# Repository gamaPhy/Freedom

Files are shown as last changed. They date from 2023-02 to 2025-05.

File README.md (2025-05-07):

# Freedom series Analog Keypads

## Tech Stack

KFC (Kicad, Freecad, C)

## Firmware

<https://github.com/gamaPhy/qmk-keyboards/tree/main/firmware/freedom>

## Images

freedom-3k

## How To

### Create an PCB outline in FreeCAD and import to Kicad

1. Create sketch in FreeCAD
2. Mirror sketch
3. Merge original sketch and mirrored sketch together
4. Export the merged sketch as `filename.dxf` (An Autodesk DXF 2D file)
5. In Kicad, import graphics as an `Edge.Cuts` layer

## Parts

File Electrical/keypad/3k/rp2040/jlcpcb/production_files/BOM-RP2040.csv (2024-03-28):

Comment | Designator | Footprint | LCSC
100n | C1,C11,C18,C19,C2,C20,C21,C22,C23,C24,C25,C26,C27,C28,C29,C3,C30,C31,C32,C33,C34,C35,C36,C37,C38,C4,C5,C6,C7,C8 | C_0402_1005Metric | C1525
47 | R7 | R_0402_1005Metric | C25118
10k | R1,R12,R13 | R_0402_1005Metric | C25744
1u | C12 | C_0402_1005Metric | C52923
12MHz | Y1 | Crystal_SMD_3225-4Pin_3.2x2.5mm | C9002
ME6212C33M5G | U1 | SOT-23-5
1u | C10 | C_1206_3216Metric
5.1k | R5 | C_0402_1005Metric
DRV5056A3QDBZR | U5 | SOT-23
BSS138 | Q1 | SOT-23
PRTR5V0U2X | U3 | SOT-143B
1k | R2 | C_0402_1005Metric
1u | C9 | C_1206_3216Metric
1u | C13 | C_0402_1005Metric
27R | R3 | C_0402_1005Metric
USB-TYPE-C-016 | P1 | USB-TYPE-C-016_Receptacle_DEALON_16P_MidMnt
nSMD050-24V | F1 | Fuse_1206_3216Metric
WS2812B | D2 | LED_WS2812B_PLCC4_5.0x5.0mm_P3.2mm
WS2812B | D5 | LED_WS2812B_PLCC4_5.0x5.0mm_P3.2mm
WS2812B | D7 | LED_WS2812B_PLCC4_5.0x5.0mm_P3.2mm
WS2812-2020 | D3 | LED_WS2812-2020
WS2812B | D9 | LED_WS2812B_PLCC4_5.0x5.0mm_P3.2mm
KAN0644-0551B1-A | SW3 | KAN0644
WS2812B | D1 | LED_WS2812B_PLCC4_5.0x5.0mm_P3.2mm
WS2812B | D6 | LED_WS2812B_PLCC4_5.0x5.0mm_P3.2mm
WS2812B | D8 | LED_WS2812B_PLCC4_5.0x5.0mm_P3.2mm
WS2812-2020 | D4 | LED_WS2812-2020
DRV5056A3QDBZR | U7 | SOT-23
TS-1187A-B-A-B | SW5 | TS-1187A
27R | R4 | C_0402_1005Metric
5.1k | R6 | C_0402_1005Metric
DRV5056A3QDBZR | U6 | SOT-23
TS-1187A-B-A-B | SW4 | TS-1187A
WS2812-2020 | D10 | LED_WS2812-2020
KAN0644-0551B1-A | SW1 | KAN0644
1k | R8 | C_0402_1005Metric
KAN0644-0551B1-A | SW2 | KAN0644
5.1k | R9 | C_0402_1005Metric
5.1k | R10 | C_0402_1005Metric
WS2812-2020 | D11 | LED_WS2812-2020
1u | C15 | C_0402_1005Metric
27p | C17 | C_0402_1005Metric
10n | C14 | C_0402_1005Metric
5.1k | R11 | C_0402_1005Metric
W25Q16JVSS | U2 | SOIC-8_5.23x5.23mm_P1.27mm
27p | C16 | C_0402_1005Metric
RP2040 | U4 | RP2040-QFN-56
WS2812B | D12 | LED_WS2812B_PLCC4_5.0x5.0mm_P3.2mm
WS2812-2020 | D14 | LED_WS2812-2020
WS2812-2020 | D13 | LED_WS2812-2020
WS2812-2020 | D15 | LED_WS2812-2020

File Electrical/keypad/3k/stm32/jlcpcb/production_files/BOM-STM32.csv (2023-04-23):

Comment | Designator | Footprint | LCSC
10n | C14 | C_0402_1005Metric | C15195
100n | C11,C2,C3,C4,C5,C6 | C_0402_1005Metric | C1525
4u7 | C1 | C_0603_1608Metric | C19666
47 | R3 | R_0402_1005Metric | C25118
10k | R4,R5,R6,R7 | R_0402_1005Metric | C25744
1u | C12,C13 | C_0402_1005Metric | C52923
12MHz | Y1 | Crystal_SMD_3225-4Pin_3.2x2.5mm | C9002
10u | C8 | C_1206_3216Metric
ME6208A44M3G | U1 | SOT-23
100n | C17 | C_0402_1005Metric
10u | C7 | C_1206_3216Metric
10u | C10 | C_1206_3216Metric
SLSS49E | U5 | SOT-23
100n | C16 | C_0402_1005Metric
100n | C15 | C_0402_1005Metric
BSS138 | Q1 | SOT-23
5.1k | R1 | C_0402_1005Metric
PRTR5V0U2X | U3 | SOT-143B
ME6212C25M5G | U2 | SOT-23-5
5.1k | R2 | C_0402_1005Metric
27p | C18 | C_0402_1005Metric
10u | C9 | C_1206_3216Metric
4u7 | C20 | C_0805_2012Metric
27p | C19 | C_0402_1005Metric
USB-TYPE-C-016 | P1 | USB-TYPE-C-016_Receptacle_DEALON_16P_MidMnt
nSMD050-24V | F1 | Fuse_1206_3216Metric
100n | C26 | C_0402_1005Metric
100n | C29 | C_0402_1005Metric
100n | C25 | C_0402_1005Metric
100n | C27 | C_0402_1005Metric
WS2812B | D2 | LED_WS2812B_PLCC4_5.0x5.0mm_P3.2mm
100n | C21 | C_0402_1005Metric
100n | C22 | C_0402_1005Metric
WS2812B | D5 | LED_WS2812B_PLCC4_5.0x5.0mm_P3.2mm
100n | C23 | C_0402_1005Metric
WS2812B | D7 | LED_WS2812B_PLCC4_5.0x5.0mm_P3.2mm
WS2812B | D3 | LED_WS2812B_PLCC4_5.0x5.0mm_P3.2mm
WS2812B | D9 | LED_WS2812B_PLCC4_5.0x5.0mm_P3.2mm
BUTT1 | SW3 | PTS647_4.5x4.5mm
WS2812B | D1 | LED_WS2812B_PLCC4_5.0x5.0mm_P3.2mm
WS2812B | D6 | LED_WS2812B_PLCC4_5.0x5.0mm_P3.2mm
WS2812B | D8 | LED_WS2812B_PLCC4_5.0x5.0mm_P3.2mm
100n | C28 | C_0402_1005Metric
WS2812B | D4 | LED_WS2812B_PLCC4_5.0x5.0mm_P3.2mm
100n | C24 | C_0402_1005Metric
GZ2012D601TF | FB1 | C_0805_2012Metric
STM32F401RCTx | U7 | LQFP-64_10x10mm_P0.5mm
Conn_01x04_Socket | J1 | PinSocket_1x04_P2.54mm_Vertical
BUTT2 | SW5 | PTS647_4.5x4.5mm
SLSS49E | U4 | SOT-23
SLSS49E | U6 | SOT-23
BUTT3 | SW4 | PTS647_4.5x4.5mm
WS2812B | D10 | LED_WS2812B_PLCC4_5.0x5.0mm_P3.2mm
100n | C30 | C_0402_1005Metric
TS-1187A-B-A-B | SW2 | TS-1187A
TS-1187A-B-A-B | SW1 | TS-1187A

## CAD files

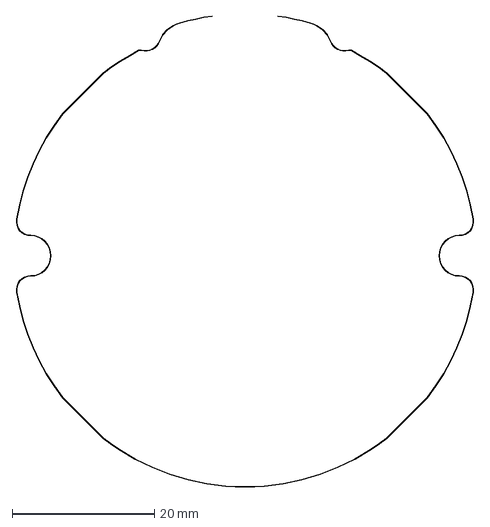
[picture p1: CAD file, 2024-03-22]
Electrical/keypad/3k/pcb-edge-cuts/edge-cuts-Shape.dxf
64.4 x 66.2 mm

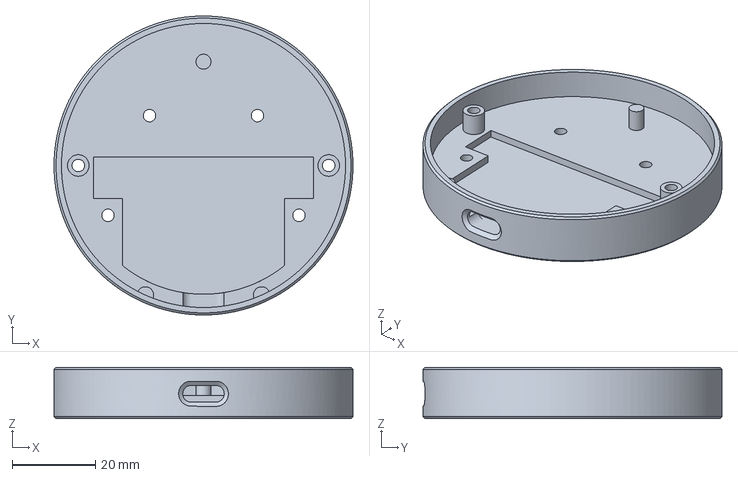
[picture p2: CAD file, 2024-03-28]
Mechanical/keypad/3k/case/Bambu/case-Body.3mf
72.0 x 72.0 x 12.4 mm

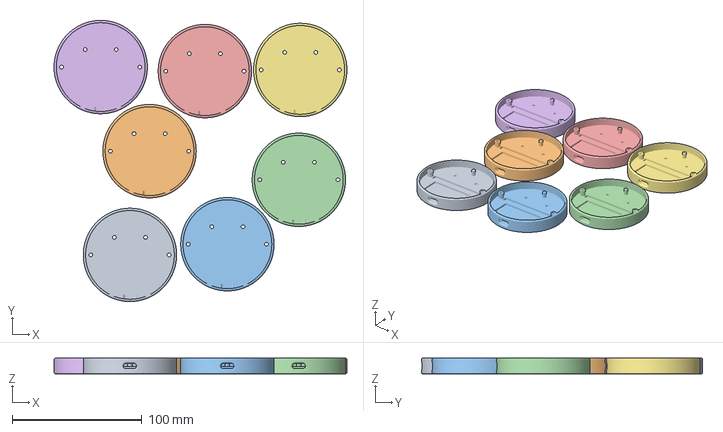
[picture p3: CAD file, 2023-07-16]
Mechanical/keypad/3k/case/Bambu/case-Body-array.3mf
225.8 x 216.7 x 12.2 mm
case-Body.stl x 7

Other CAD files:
Mechanical/keypad/3k/case/case.FCStd
Electrical/keypad/3k/pcb-edge-cuts/edge-cuts.FCStd
Mechanical/keypad/3k/case/case-Body.3mf
Mechanical/keypad/3k/case/case-Body-pla-plus.3mf
Mechanical/keypad/3k/case/case-Body.stl

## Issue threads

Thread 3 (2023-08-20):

HE sensor output value changes depending on LED settings.

tlietz, 2023-08-20:
Should try testing out switching regulators, or find a way to compensate the changes in firmware by detecting when LED settings are changed and getting a new reading for "unpressed".

tlietz, 2023-10-31:
Oversampling was sufficient

Closed 2023-10-31.

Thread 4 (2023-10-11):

Some LED are directly under bare fr4 material of plate

tlietz, 2023-10-11:
This causes jarring light when LED brightness is high.

Should change location of triangles on the plate

tlietz, 2023-11-20:
Actually isn't bad the way it is, can be reopened later if there are complaints about it

Closed 2023-11-20.

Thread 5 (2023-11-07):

Add LED on GPIO25

tlietz, 2023-11-07:
The PICO has an LED on GPIO25. This could be useful for debugging. However, there may be an easy way to repurpose the other LEDs we currently use.

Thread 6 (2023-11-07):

External EEPROM for sensor calibration

tlietz, 2023-11-07:
An external eeprom can be used to store sensor calibration values so that the internal eeprom (or external flash for rp2040) can be factory reset without affecting the calibration values. This will become more important as the number of keys increase.

Closed 2024-03-13.

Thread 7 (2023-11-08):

Uneven underglow

tlietz, 2023-11-08:
The underglow looks uneven, decreasing the radius of the pcb would help. There are already two screws to secure the PCB, so the pcb doesn't need to touch the case walls at all.

tlietz, 2024-03-13:
Decreased radius of pcb to about 2mm less than inner case

Closed 2024-03-13.

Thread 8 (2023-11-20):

Add pads or plated thru holes from rp2040 GPIO pins

tlietz, 2023-11-20:
Breakout some more pins of the rp2040 so that peripherals can be easily hand-wired to the unused I2C and SPI busses.  Also makes it easier to repurpose the board.

tlietz, 2024-03-13:
Added I2c0 and I2c1 plated through-holes with 2.54mm pitch. Decided not to breakout any SPI because it would be hard to find room, and SPI is not that suitable for hand-wiring due to the relatively fast frequencies.

Closed 2024-03-13.

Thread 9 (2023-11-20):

Use non-addressable rgb LEDs and have an IC controller driving them

tlietz, 2023-11-20:
How does power consumption between the LEDs compare? Can more LEDs be used, resulting in more consistent gradients while LED are on?

tlietz, 2024-03-13:
Not needed for small keypad

Closed 2024-03-13.

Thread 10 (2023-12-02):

Temperature drift

tlietz, 2023-12-02:
There is considerable temperature drift when LEDs are on. How can this be improved on a PCB level? How much can it be compensated for in firmware?

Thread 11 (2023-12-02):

Remove all power sources except 3v3

tlietz, 2023-12-02:
Boards have been tested using the 3v3 LDO to power RP2040, the ADC, and the HE sensors. Found that it works just as well as using the 4v4 and 2v5 LDOs since the range of the HE sensor outputs is still large enough.

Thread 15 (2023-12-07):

Find better button solution

tlietz, 2023-12-07:
The current plastic buttons are only 2.4mm in diameter, and I'm developing calluses from using them.
The only plastic buttons that feel good are ones that have a diameter of at least 3mm. However, the base is usually too high to fit between the PCB and plate.

Can also look into silicone, rubber, or plastic caps

Update PCB and plate accordingly

tlietz, 2023-12-07:
Might also be able to use the 4.5x4.5mm buttons that have 2.5mm stem diameter with these caps:
https://www.aliexpress.us/item/3256804597174923.html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,scm-url:1007.40000.326746.0,pvid:f3fe78c0-eed2-4f92-ae2c-fd7d8d456037,tpp_buckets:668%232846%238114%23706&pdp_npi=4%40dis%21USD%214.00%213.6%21%21%214.00%21%21%402101e9ec17019235043287144e413f%2112000030471356784%21rec%21US%21%21AB

Closed 2024-03-07.

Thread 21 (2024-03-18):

Test making only half of the printed standoff for improved lighting

tlietz, 2024-03-18:

tlietz, 2024-03-23:
Only needed if the new LED placement prove to be insufficient

tlietz, 2024-04-27:
no need with current led configuration

Closed 2024-04-27.

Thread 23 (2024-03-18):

Change per-key backlight leds to 2x2mm size

tlietz, 2024-03-18:
Some switches have a thin plastic line that prevents them from being used with the 5050 led package size

Closed 2024-03-22.

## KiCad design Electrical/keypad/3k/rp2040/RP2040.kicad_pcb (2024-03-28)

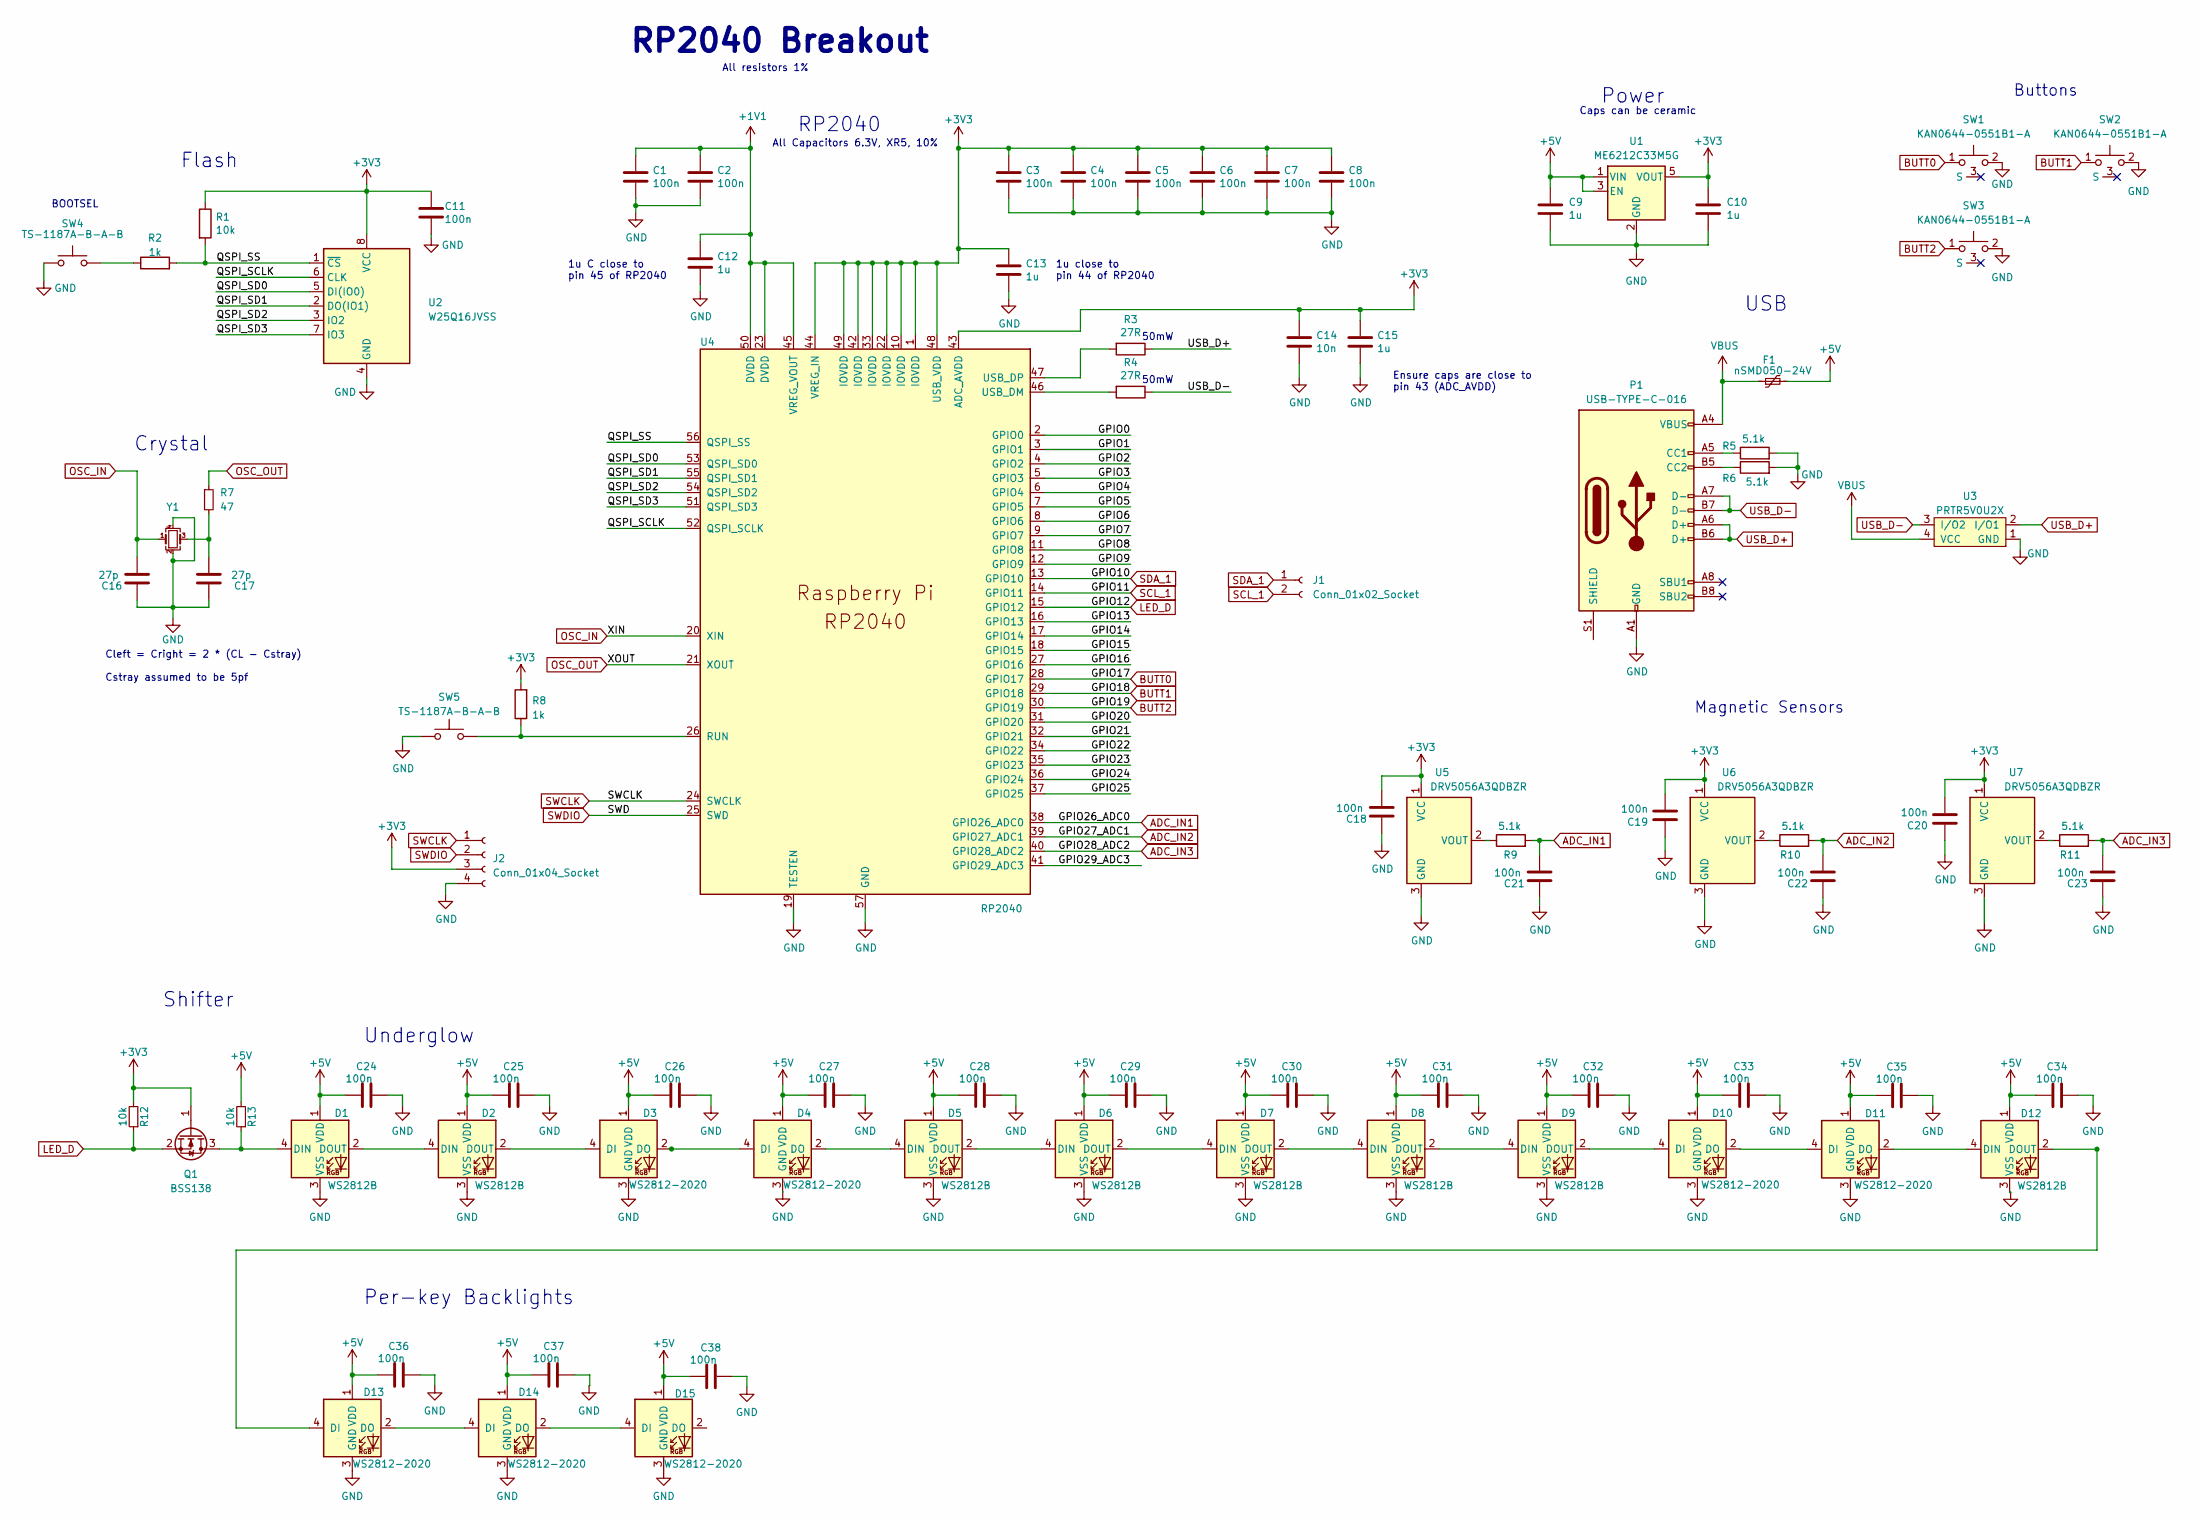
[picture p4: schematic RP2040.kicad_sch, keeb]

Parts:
C1, C2, C3, C4, C5, C6, C7, C8, C11, C18, C19, C20, C21, C22, C23, C24, C25, C26, C27, C28, C29, C30, C31, C32, C33, C34, C35, C36, C37, C38: 100n; C_0402_1005Metric
C9, C10: 1u; C_1206_3216Metric
C12, C13, C15: 1u; C_0402_1005Metric
C14: 10n; C_0402_1005Metric
C16, C17: 27p; C_0402_1005Metric
D1, D2, D5, D6, D7, D8, D9, D12: WS2812B; LED_WS2812B_PLCC4_5.0x5.0mm_P3.2mm
D3, D4, D10, D11, D13, D14, D15: WS2812-2020; LED_WS2812-2020; PARTREV V1.3
F1: nSMD050-24V; Fuse_1206_3216Metric
J1: Conn_01x02_Socket; PinSocket_1x02_P2.54mm_Vertical
J2: Conn_01x04_Socket; PinSocket_1x04_P2.54mm_Vertical
P1: USB-TYPE-C-016; USB-TYPE-C-016_Receptacle_DEALON_16P_MidMnt
Q1: BSS138; SOT-23
R1: 10k; R_0402_1005Metric
R2, R8: 1k; C_0402_1005Metric
R3, R4: 27R; C_0402_1005Metric
R5, R6, R9, R10, R11: 5.1k; C_0402_1005Metric
R7: 47; R_0402_1005Metric; LCSC Part # C25118
R12, R13: 10k; R_0402_1005Metric; LCSC Part # C25744
SW1, SW2, SW3: KAN0644-0551B1-A; KAN0644
SW4, SW5: TS-1187A-B-A-B; TS-1187A
U1: ME6212C33M5G; SOT-23-5
U2: W25Q16JVSS; SOIC-8_5.23x5.23mm_P1.27mm
U3: PRTR5V0U2X; SOT-143B
U4: RP2040; RP2040-QFN-56
U5, U6, U7: DRV5056A3QDBZR; SOT-23
Y1: 12MHz; Crystal_SMD_3225-4Pin_3.2x2.5mm; LCSC Part # C9002

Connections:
+1V1: C1.1, C2.1, C12.1, U4.23 (DVDD), U4.45 (VREG_VOUT), U4.50 (DVDD)
+3V3: C3.1, C4.1, C5.1, C6.1, C7.1, C8.1, C10.1, C11.1, C13.1, C14.1, C15.1, C18.2, C19.2, C20.2, J2.3, Q1.1 (G), R1.1, R8.2, R12.2, U1.5 (VOUT), U2.8 (VCC), U4.1 (IOVDD), U4.10 (IOVDD), U4.22 (IOVDD), U4.33 (IOVDD), U4.42 (IOVDD), U4.43 (ADC_AVDD), U4.44 (VREG_IN), U4.48 (USB_VDD), U4.49 (IOVDD), U5.1 (VCC), U6.1 (VCC), U7.1 (VCC)
+5V: C9.1, C24.1, C25.1, C26.1, C27.1, C28.1, C29.1, C30.1, C31.1, C32.1, C33.1, C34.1, C35.1, C36.1, C37.1, C38.1, D1.1 (VDD), D2.1 (VDD), D3.1 (VDD), D4.1 (VDD), D5.1 (VDD), D6.1 (VDD), D7.1 (VDD), D8.1 (VDD), D9.1 (VDD), D10.1 (VDD), D11.1 (VDD), D12.1 (VDD), D13.1 (VDD), D14.1 (VDD), D15.1 (VDD), F1.2, R13.2, U1.1 (VIN), U1.3 (EN)
/GPIO0: U4.2 (GPIO0)
/GPIO1: U4.3 (GPIO1)
/GPIO2: U4.4 (GPIO2)
/GPIO3: U4.5 (GPIO3)
/GPIO4: U4.6 (GPIO4)
/GPIO5: U4.7 (GPIO5)
/GPIO6: U4.8 (GPIO6)
/GPIO7: U4.9 (GPIO7)
/GPIO8: U4.11 (GPIO8)
/GPIO9: U4.12 (GPIO9)
/GPIO13: U4.16 (GPIO13)
/GPIO14: U4.17 (GPIO14)
/GPIO15: U4.18 (GPIO15)
/GPIO16: U4.27 (GPIO16)
/GPIO20: U4.31 (GPIO20)
/GPIO21: U4.32 (GPIO21)
/GPIO22: U4.34 (GPIO22)
/GPIO23: U4.35 (GPIO23)
/GPIO24: U4.36 (GPIO24)
/GPIO25: U4.37 (GPIO25)
/GPIO29_ADC3: U4.41 (GPIO29_ADC3)
/QSPI_SCLK: U2.6 (CLK), U4.52 (QSPI_SCLK)
/QSPI_SD0: U2.5 (DI(IO0)), U4.53 (QSPI_SD0)
/QSPI_SD1: U2.2 (DO(IO1)), U4.55 (QSPI_SD1)
/QSPI_SD2: U2.3 (IO2), U4.54 (QSPI_SD2)
/QSPI_SD3: U2.7 (IO3), U4.51 (QSPI_SD3)
/QSPI_SS: R1.2, R2.2, U2.1 (~CS), U4.56 (QSPI_SS)
ADC_IN1: C21.2, R9.2, U4.38 (GPIO26_ADC0)
ADC_IN2: C22.2, R10.2, U4.39 (GPIO27_ADC1)
ADC_IN3: C23.2, R11.2, U4.40 (GPIO28_ADC2)
BUTT0: SW1.1, U4.28 (GPIO17)
BUTT1: SW2.1, U4.29 (GPIO18)
BUTT2: SW3.1, U4.30 (GPIO19)
GND: C1.2, C2.2, C3.2, C4.2, C5.2, C6.2, C7.2, C8.2, C9.2, C10.2, C11.2, C12.2, C13.2, C14.2, C15.2, C16.1, C17.1, C18.1, C19.1, C20.1, C21.1, C22.1, C23.1, C24.2, C25.2, C26.2, C27.2, C28.2, C29.2, C30.2, C31.2, C32.2, C33.2, C34.2, C35.2, C36.2, C37.2, C38.2, D1.3 (VSS), D2.3 (VSS), D3.3 (GND), D4.3 (GND), D5.3 (VSS), D6.3 (VSS), D7.3 (VSS), D8.3 (VSS), D9.3 (VSS), D10.3 (GND), D11.3 (GND), D12.3 (VSS), D13.3 (GND), D14.3 (GND), D15.3 (GND), J2.4, P1.A1 (GND), P1.A12 (GND), P1.B1 (GND), P1.B12 (GND), R5.2, R6.2, SW1.2, SW2.2, SW3.2, SW4.1, SW5.1, U1.2 (GND), U2.4 (GND), U3.1 (GND), U4.19 (TESTEN), U4.57 (GND), U5.3 (GND), U6.3 (GND), U7.3 (GND), Y1.2, Y1.4
LED_D: Q1.2 (S), R12.1, U4.15 (GPIO12)
unnamed: C17.2, R7.2, Y1.3
unnamed: D1.4 (DIN), Q1.3 (D), R13.1
unnamed: D1.2 (DOUT), D2.4 (DIN)
unnamed: D2.2 (DOUT), D3.4 (DI)
unnamed: D3.2 (DO), D4.4 (DI)
unnamed: D4.2 (DO), D5.4 (DIN)
unnamed: D5.2 (DOUT), D6.4 (DIN)
unnamed: D6.2 (DOUT), D7.4 (DIN)
unnamed: D7.2 (DOUT), D8.4 (DIN)
unnamed: D8.2 (DOUT), D9.4 (DIN)
unnamed: D9.2 (DOUT), D10.4 (DI)
unnamed: D10.2 (DO), D11.4 (DI)
unnamed: D11.2 (DO), D12.4 (DIN)
unnamed: D12.2 (DOUT), D13.4 (DI)
unnamed: D13.2 (DO), D14.4 (DI)
unnamed: D14.2 (DO), D15.4 (DI)
unnamed: P1.A5 (CC1), R5.1
unnamed: P1.B5 (CC2), R6.1
unnamed: R2.1, SW4.2
unnamed: R8.1, SW5.2, U4.26 (RUN)
unnamed: R4.2, U4.46 (USB_DM)
unnamed: R3.2, U4.47 (USB_DP)
unnamed: R9.1, U5.2 (VOUT)
unnamed: R10.1, U6.2 (VOUT)
unnamed: R11.1, U7.2 (VOUT)
OSC_IN: C16.2, U4.20 (XIN), Y1.1
OSC_OUT: R7.1, U4.21 (XOUT)
SCL_1: J1.2, U4.14 (GPIO11)
SDA_1: J1.1, U4.13 (GPIO10)
SWCLK: J2.1, U4.24 (SWCLK)
SWDIO: J2.2, U4.25 (SWD)
USB_D+: P1.A6 (D+), P1.B6 (D+), R3.1, U3.2 (I/O1)
USB_D-: P1.A7 (D-), P1.B7 (D-), R4.1, U3.3 (I/O2)
VBUS: F1.1, P1.A4 (VBUS), P1.A9 (VBUS), P1.B4 (VBUS), P1.B9 (VBUS), U3.4 (VCC)

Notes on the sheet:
50mW
RP2040 Breakout
Underglow
Crystal
Magnetic Sensors
Per-key Backlights
All Capacitors 6.3V, XR5, 10%
USB
Flash
Ensure caps are close to pin 43 (ADC_AVDD)
1u close to pin 44 of RP2040
1u C close to pin 45 of RP2040
Caps can be ceramic
All resistors 1%
Power
Buttons
Shifter
RP2040
Cleft = Cright = 2 * (CL - Cstray) Cstray assumed to be 5pf
BOOTSEL

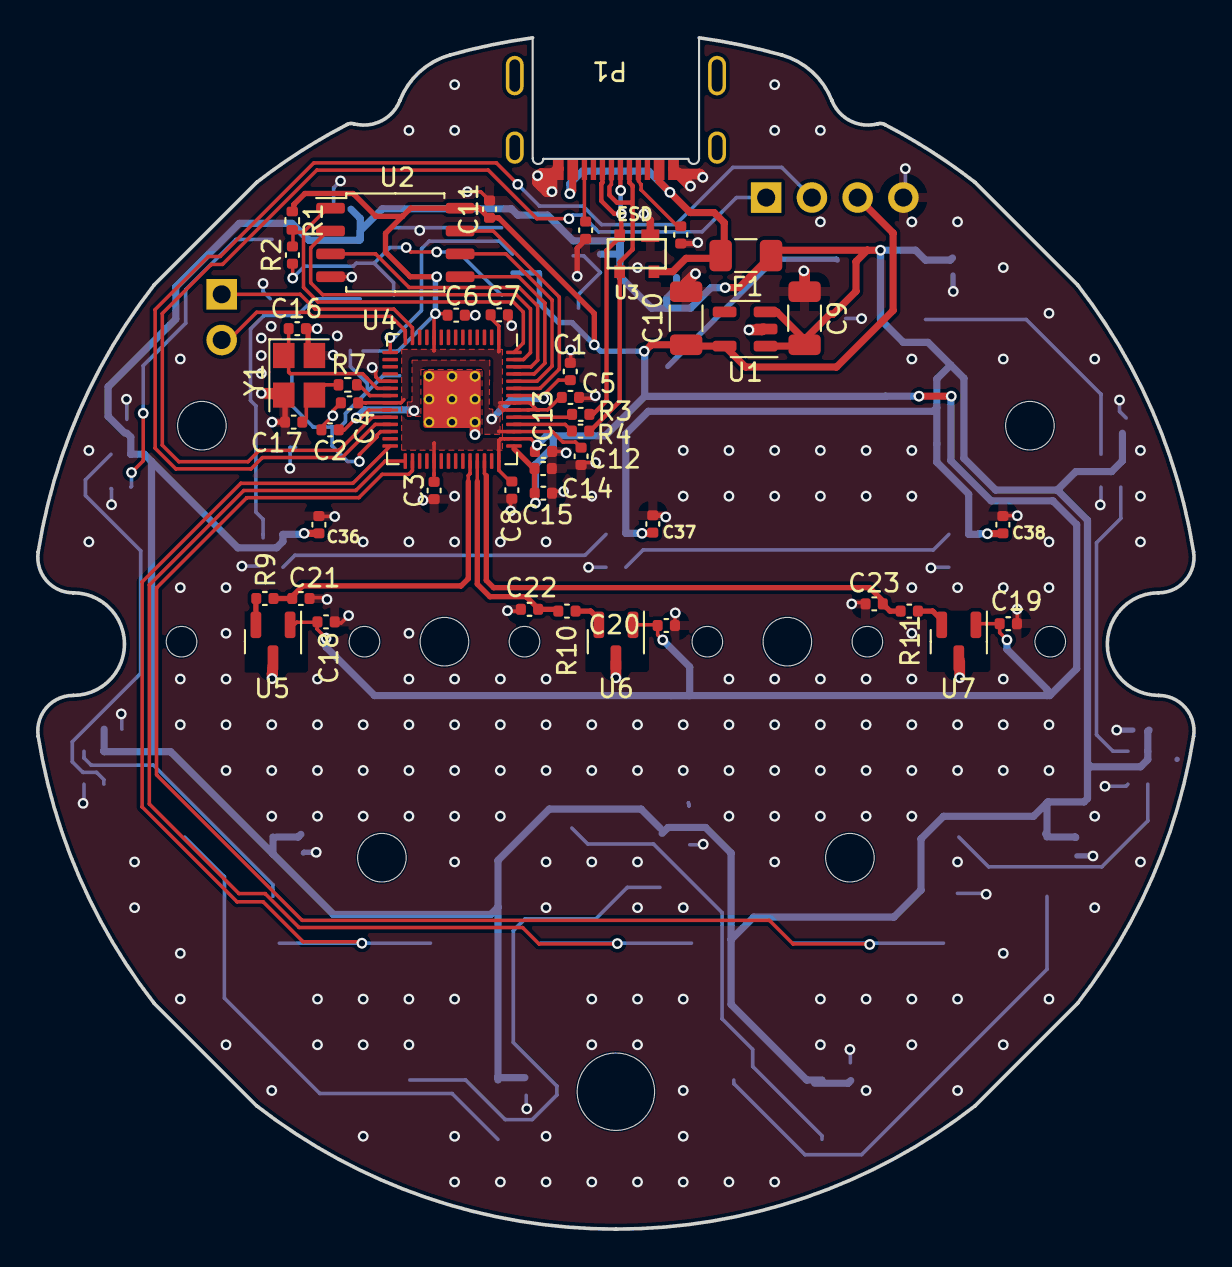
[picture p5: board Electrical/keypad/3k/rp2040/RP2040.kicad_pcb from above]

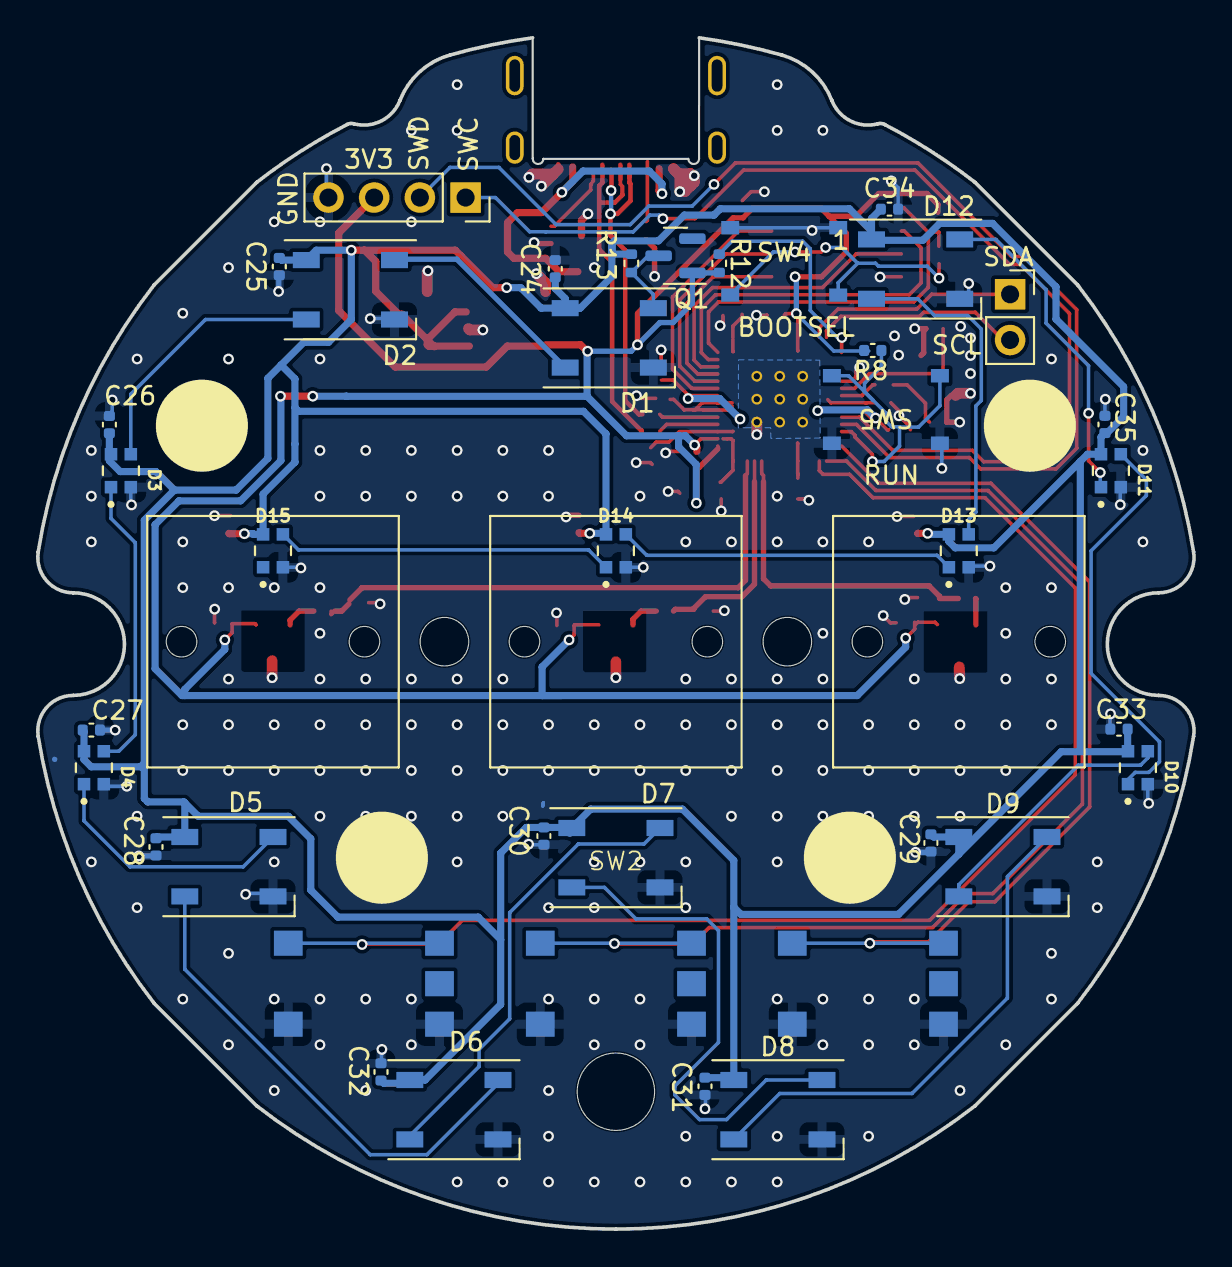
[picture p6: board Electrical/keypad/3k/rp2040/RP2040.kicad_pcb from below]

Board: 4 copper layers, 64.2 x 66.2 mm, 84 parts (38 on the bottom side), 51 nets.

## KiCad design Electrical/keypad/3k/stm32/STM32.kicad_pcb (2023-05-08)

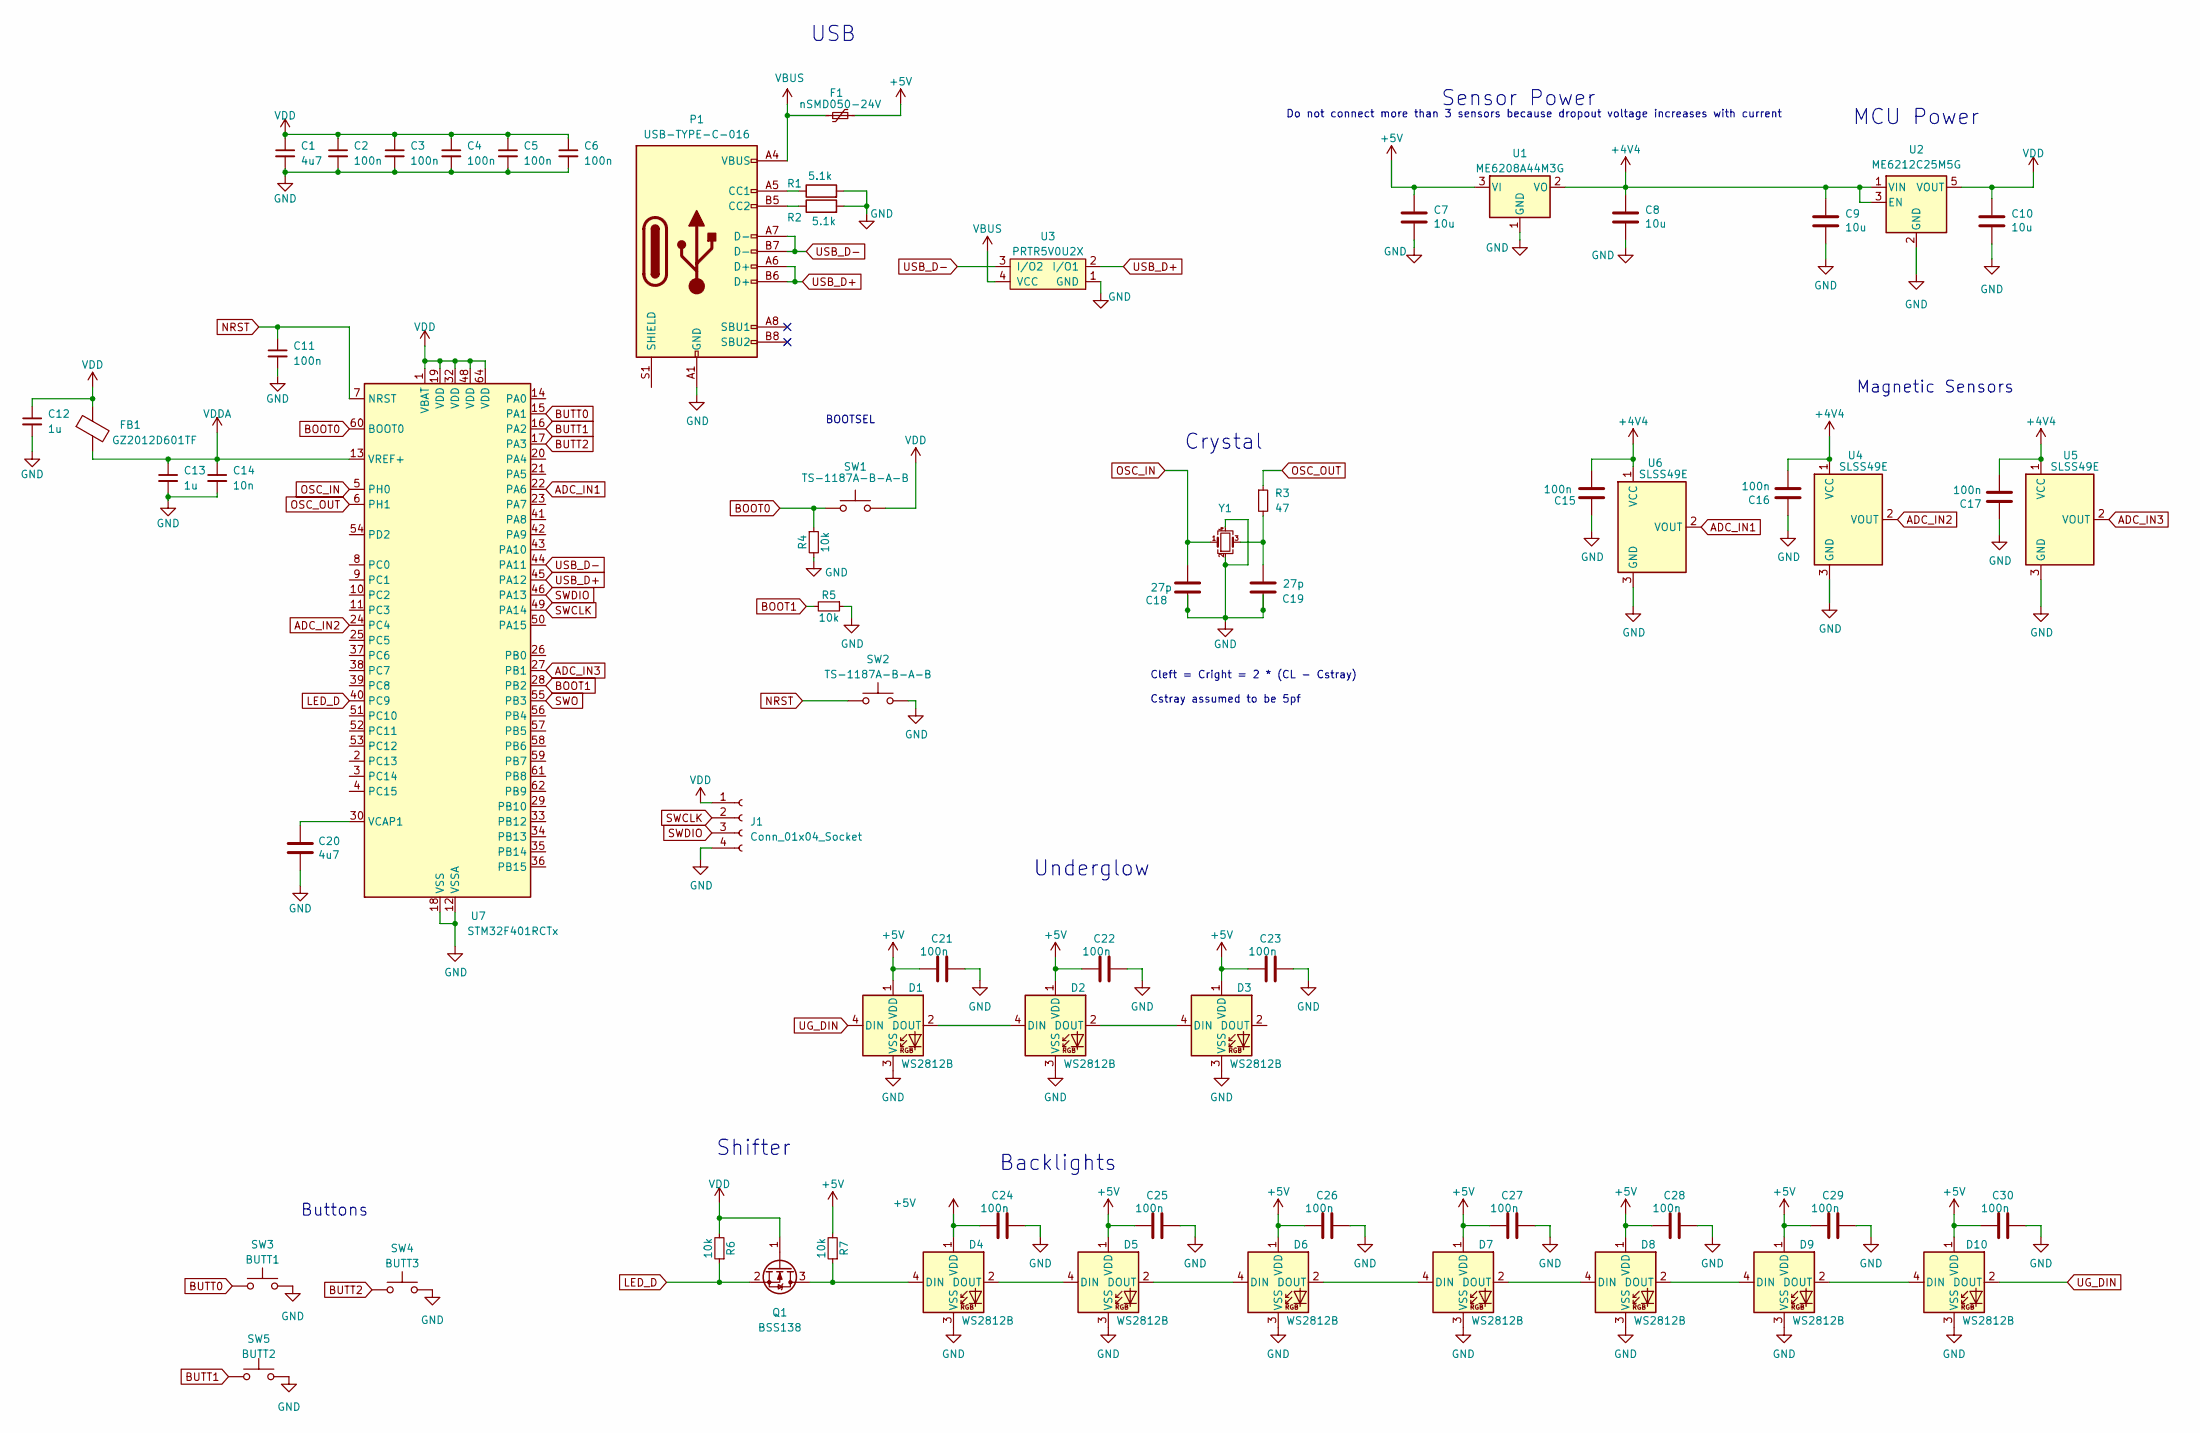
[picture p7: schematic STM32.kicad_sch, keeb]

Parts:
C1: 4u7; C_0603_1608Metric; LCSC Part # C19666
C2, C3, C4, C5, C6, C11: 100n; C_0402_1005Metric; LCSC Part # C1525
C7, C8, C9, C10: 10u; C_1206_3216Metric
C12, C13: 1u; C_0402_1005Metric; LCSC Part # C52923
C14: 10n; C_0402_1005Metric; LCSC Part # C15195
C15, C16, C17, C21, C22, C23, C24, C25, C26, C27, C28, C29, C30: 100n; C_0402_1005Metric
C18, C19: 27p; C_0402_1005Metric
C20: 4u7; C_0805_2012Metric
D1, D2, D3, D4, D5, D6, D7, D8, D9, D10: WS2812B; LED_WS2812B_PLCC4_5.0x5.0mm_P3.2mm
F1: nSMD050-24V; Fuse_1206_3216Metric
FB1: GZ2012D601TF; C_0805_2012Metric
J1: Conn_01x04_Socket; PinSocket_1x04_P2.54mm_Vertical
P1: USB-TYPE-C-016; USB-TYPE-C-016_Receptacle_DEALON_16P_MidMnt
Q1: BSS138; SOT-23
R1, R2: 5.1k; C_0402_1005Metric
R3: 47; R_0402_1005Metric; LCSC Part # C25118
R4, R5, R6, R7: 10k; R_0402_1005Metric; LCSC Part # C25744
SW1, SW2: TS-1187A-B-A-B; TS-1187A
SW3: BUTT1; SW_Push_1P1T_NO_6x6mm_H9.5mm
SW4: BUTT3; SW_Push_1P1T_NO_6x6mm_H9.5mm
SW5: BUTT2; SW_Push_1P1T_NO_6x6mm_H9.5mm
U1: ME6208A44M3G; SOT-23-3
U2: ME6212C25M5G; SOT-23-5
U3: PRTR5V0U2X; SOT-143B
U4, U5, U6: SLSS49E; SOT-23
U7: STM32F401RCTx; LQFP-64_10x10mm_P0.5mm
Y1: 12MHz; Crystal_SMD_3225-4Pin_3.2x2.5mm; LCSC Part # C9002

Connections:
+4V4: C8.1, C9.1, C15.2, C16.2, C17.2, U1.2 (VO), U2.1 (VIN), U2.3 (EN), U4.1 (VCC), U5.1 (VCC), U6.1 (VCC)
+5V: C7.1, C21.1, C22.1, C23.1, C24.1, C25.1, C26.1, C27.1, C28.1, C29.1, C30.1, D1.1 (VDD), D2.1 (VDD), D3.1 (VDD), D4.1 (VDD), D5.1 (VDD), D6.1 (VDD), D7.1 (VDD), D8.1 (VDD), D9.1 (VDD), D10.1 (VDD), F1.2, R7.2, U1.3 (VI)
ADC_IN1: U6.2 (VOUT), U7.22 (PA6)
ADC_IN2: U4.2 (VOUT), U7.24 (PC4)
ADC_IN3: U5.2 (VOUT), U7.27 (PB1)
BOOT0: R4.1, SW1.1, U7.60 (BOOT0)
BOOT1: R5.2, U7.28 (PB2)
BUTT0: SW3.1, U7.15 (PA1)
BUTT1: SW5.1, U7.16 (PA2)
BUTT2: SW4.1, U7.17 (PA3)
GND: C1.2, C2.2, C3.2, C4.2, C5.2, C6.2, C7.2, C8.2, C9.2, C10.2, C11.2, C12.2, C13.2, C14.2, C15.1, C16.1, C17.1, C18.1, C19.1, C20.2, C21.2, C22.2, C23.2, C24.2, C25.2, C26.2, C27.2, C28.2, C29.2, C30.2, D1.3 (VSS), D2.3 (VSS), D3.3 (VSS), D4.3 (VSS), D5.3 (VSS), D6.3 (VSS), D7.3 (VSS), D8.3 (VSS), D9.3 (VSS), D10.3 (VSS), J1.4, P1.A1 (GND), P1.A12 (GND), P1.B1 (GND), P1.B12 (GND), R1.2, R2.2, R4.2, R5.1, SW2.2, SW3.2, SW4.2, SW5.2, U1.1 (GND), U2.2 (GND), U3.1 (GND), U4.3 (GND), U5.3 (GND), U6.3 (GND), U7.12 (VSSA), U7.18 (VSS), U7.31 (VSS), U7.47 (VSS), U7.63 (VSS), Y1.2, Y1.4
LED_D: Q1.2 (S), R6.1, U7.40 (PC9)
NRST: C11.1, SW2.1, U7.7 (NRST)
unnamed: C19.2, R3.2, Y1.3
unnamed: D1.2 (DOUT), D2.4 (DIN)
unnamed: D2.2 (DOUT), D3.4 (DIN)
unnamed: D4.4 (DIN), Q1.3 (D), R7.1
unnamed: D4.2 (DOUT), D5.4 (DIN)
unnamed: D5.2 (DOUT), D6.4 (DIN)
unnamed: D6.2 (DOUT), D7.4 (DIN)
unnamed: D7.2 (DOUT), D8.4 (DIN)
unnamed: D8.2 (DOUT), D9.4 (DIN)
unnamed: D9.2 (DOUT), D10.4 (DIN)
unnamed: P1.A5 (CC1), R1.1
unnamed: P1.B5 (CC2), R2.1
unnamed: C20.1, U7.30 (VCAP1)
OSC_IN: C18.2, U7.5 (PH0), Y1.1
OSC_OUT: R3.1, U7.6 (PH1)
SWCLK: J1.2, U7.49 (PA14)
SWDIO: J1.3, U7.46 (PA13)
SWO: U7.55 (PB3)
UG_DIN: D1.4 (DIN), D10.2 (DOUT)
USB_D+: P1.A6 (D+), P1.B6 (D+), U3.2 (I/O1), U7.45 (PA12)
USB_D-: P1.A7 (D-), P1.B7 (D-), U3.3 (I/O2), U7.44 (PA11)
VBUS: F1.1, P1.A4 (VBUS), P1.A9 (VBUS), P1.B4 (VBUS), P1.B9 (VBUS), U3.4 (VCC)
VDD: C1.1, C2.1, C3.1, C4.1, C5.1, C6.1, C10.1, C12.1, FB1.1, J1.1, Q1.1 (G), R6.2, SW1.2, U2.5 (VOUT), U7.1 (VBAT), U7.19 (VDD), U7.32 (VDD), U7.48 (VDD), U7.64 (VDD)
VDDA: C13.1, C14.1, FB1.2, U7.13 (VREF+)

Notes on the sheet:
Sensor Power
Do not connect more than 3 sensors because dropout voltage increases with current
BOOTSEL
Backlights
Crystal
MCU Power
Magnetic Sensors
Underglow
USB
Buttons
Shifter
Cleft = Cright = 2 * (CL - Cstray) Cstray assumed to be 5pf

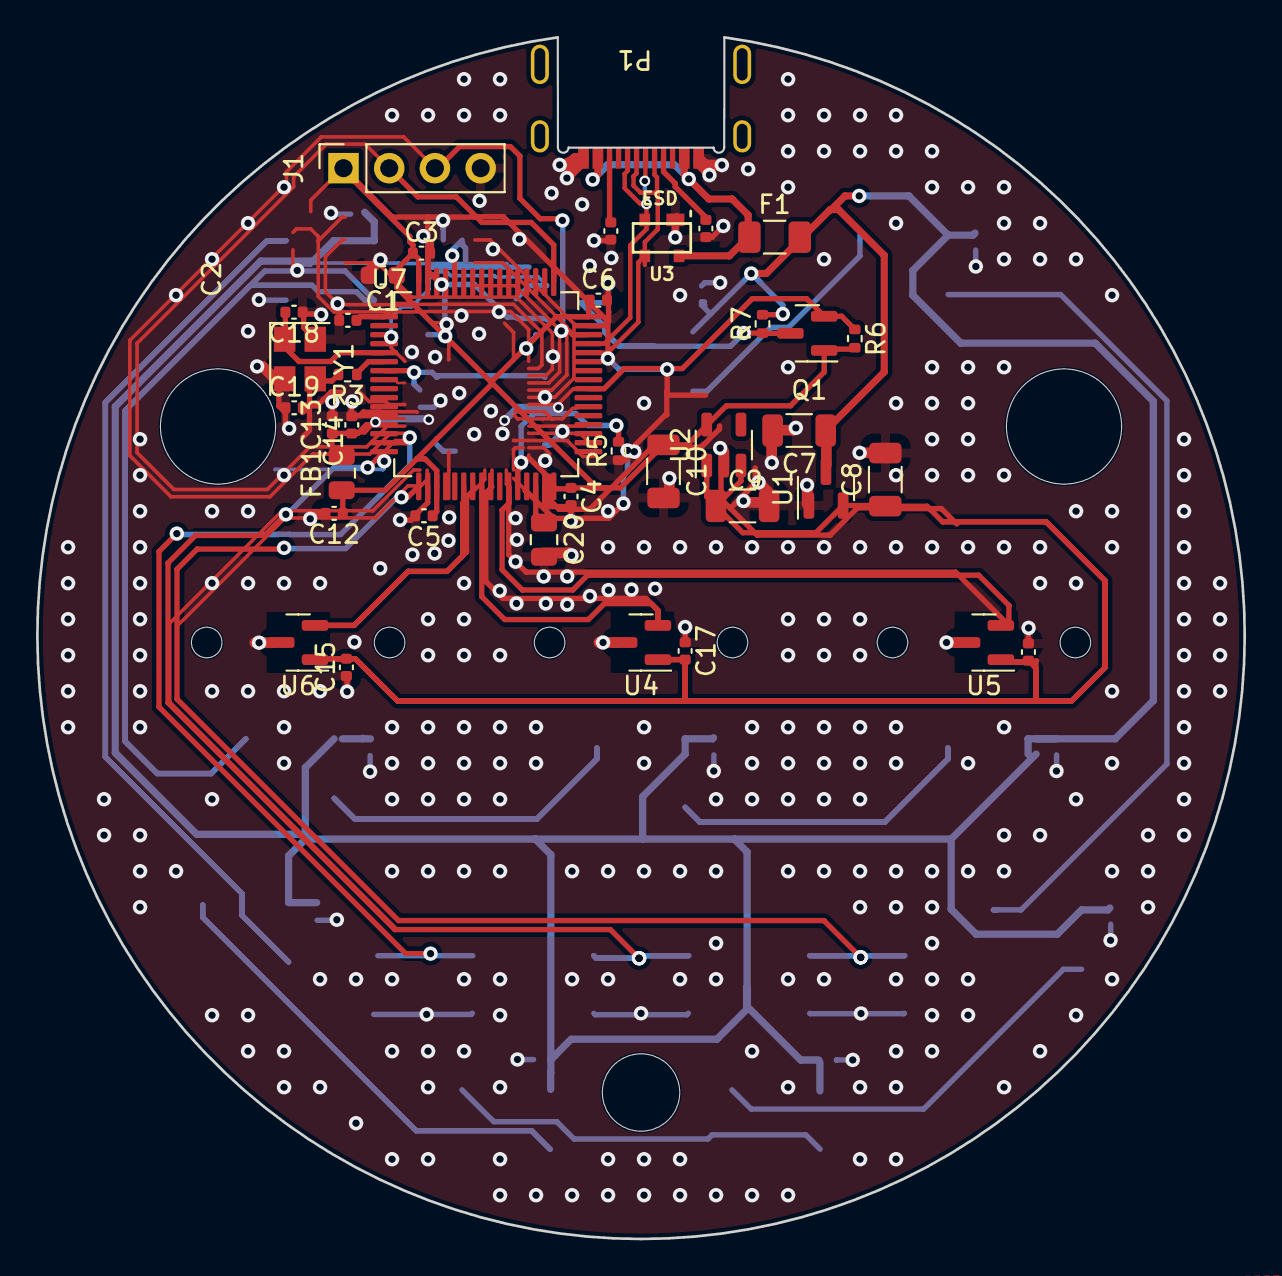
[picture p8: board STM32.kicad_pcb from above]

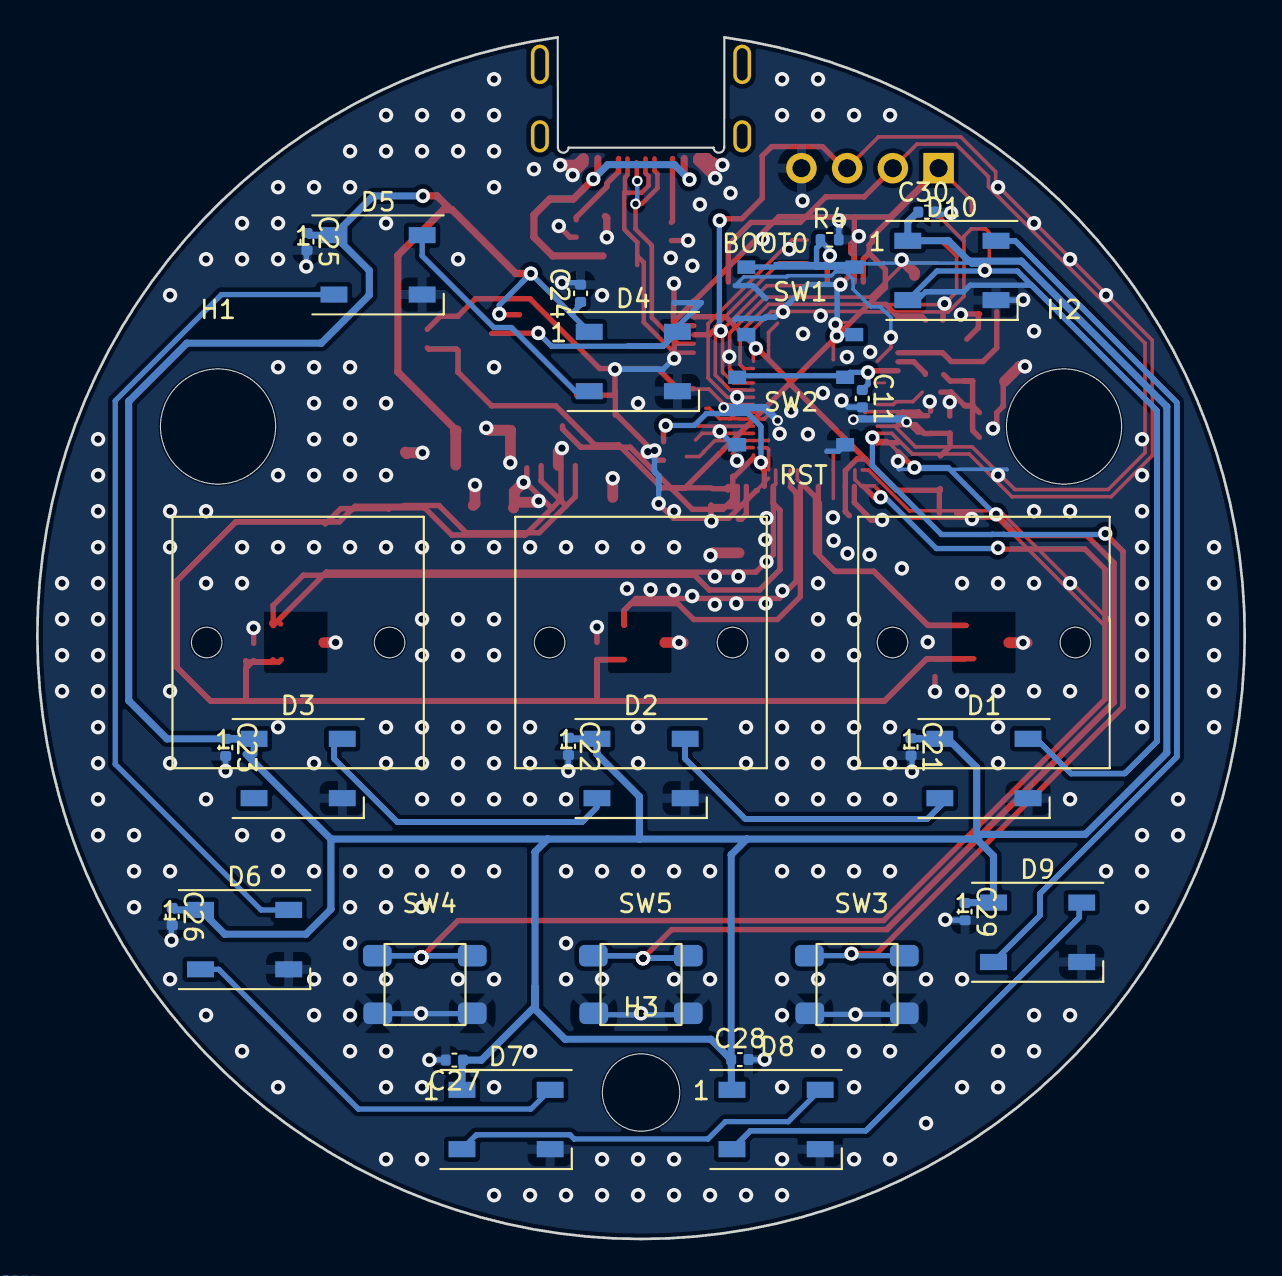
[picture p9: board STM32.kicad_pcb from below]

Board: 4 copper layers, 67.1 x 66.8 mm, 68 parts (30 on the bottom side), 36 nets.

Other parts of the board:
H1, H2: MountingHole_6.4mm_M6_DIN965
H3: MountingHole_4.3mm_M4_DIN965

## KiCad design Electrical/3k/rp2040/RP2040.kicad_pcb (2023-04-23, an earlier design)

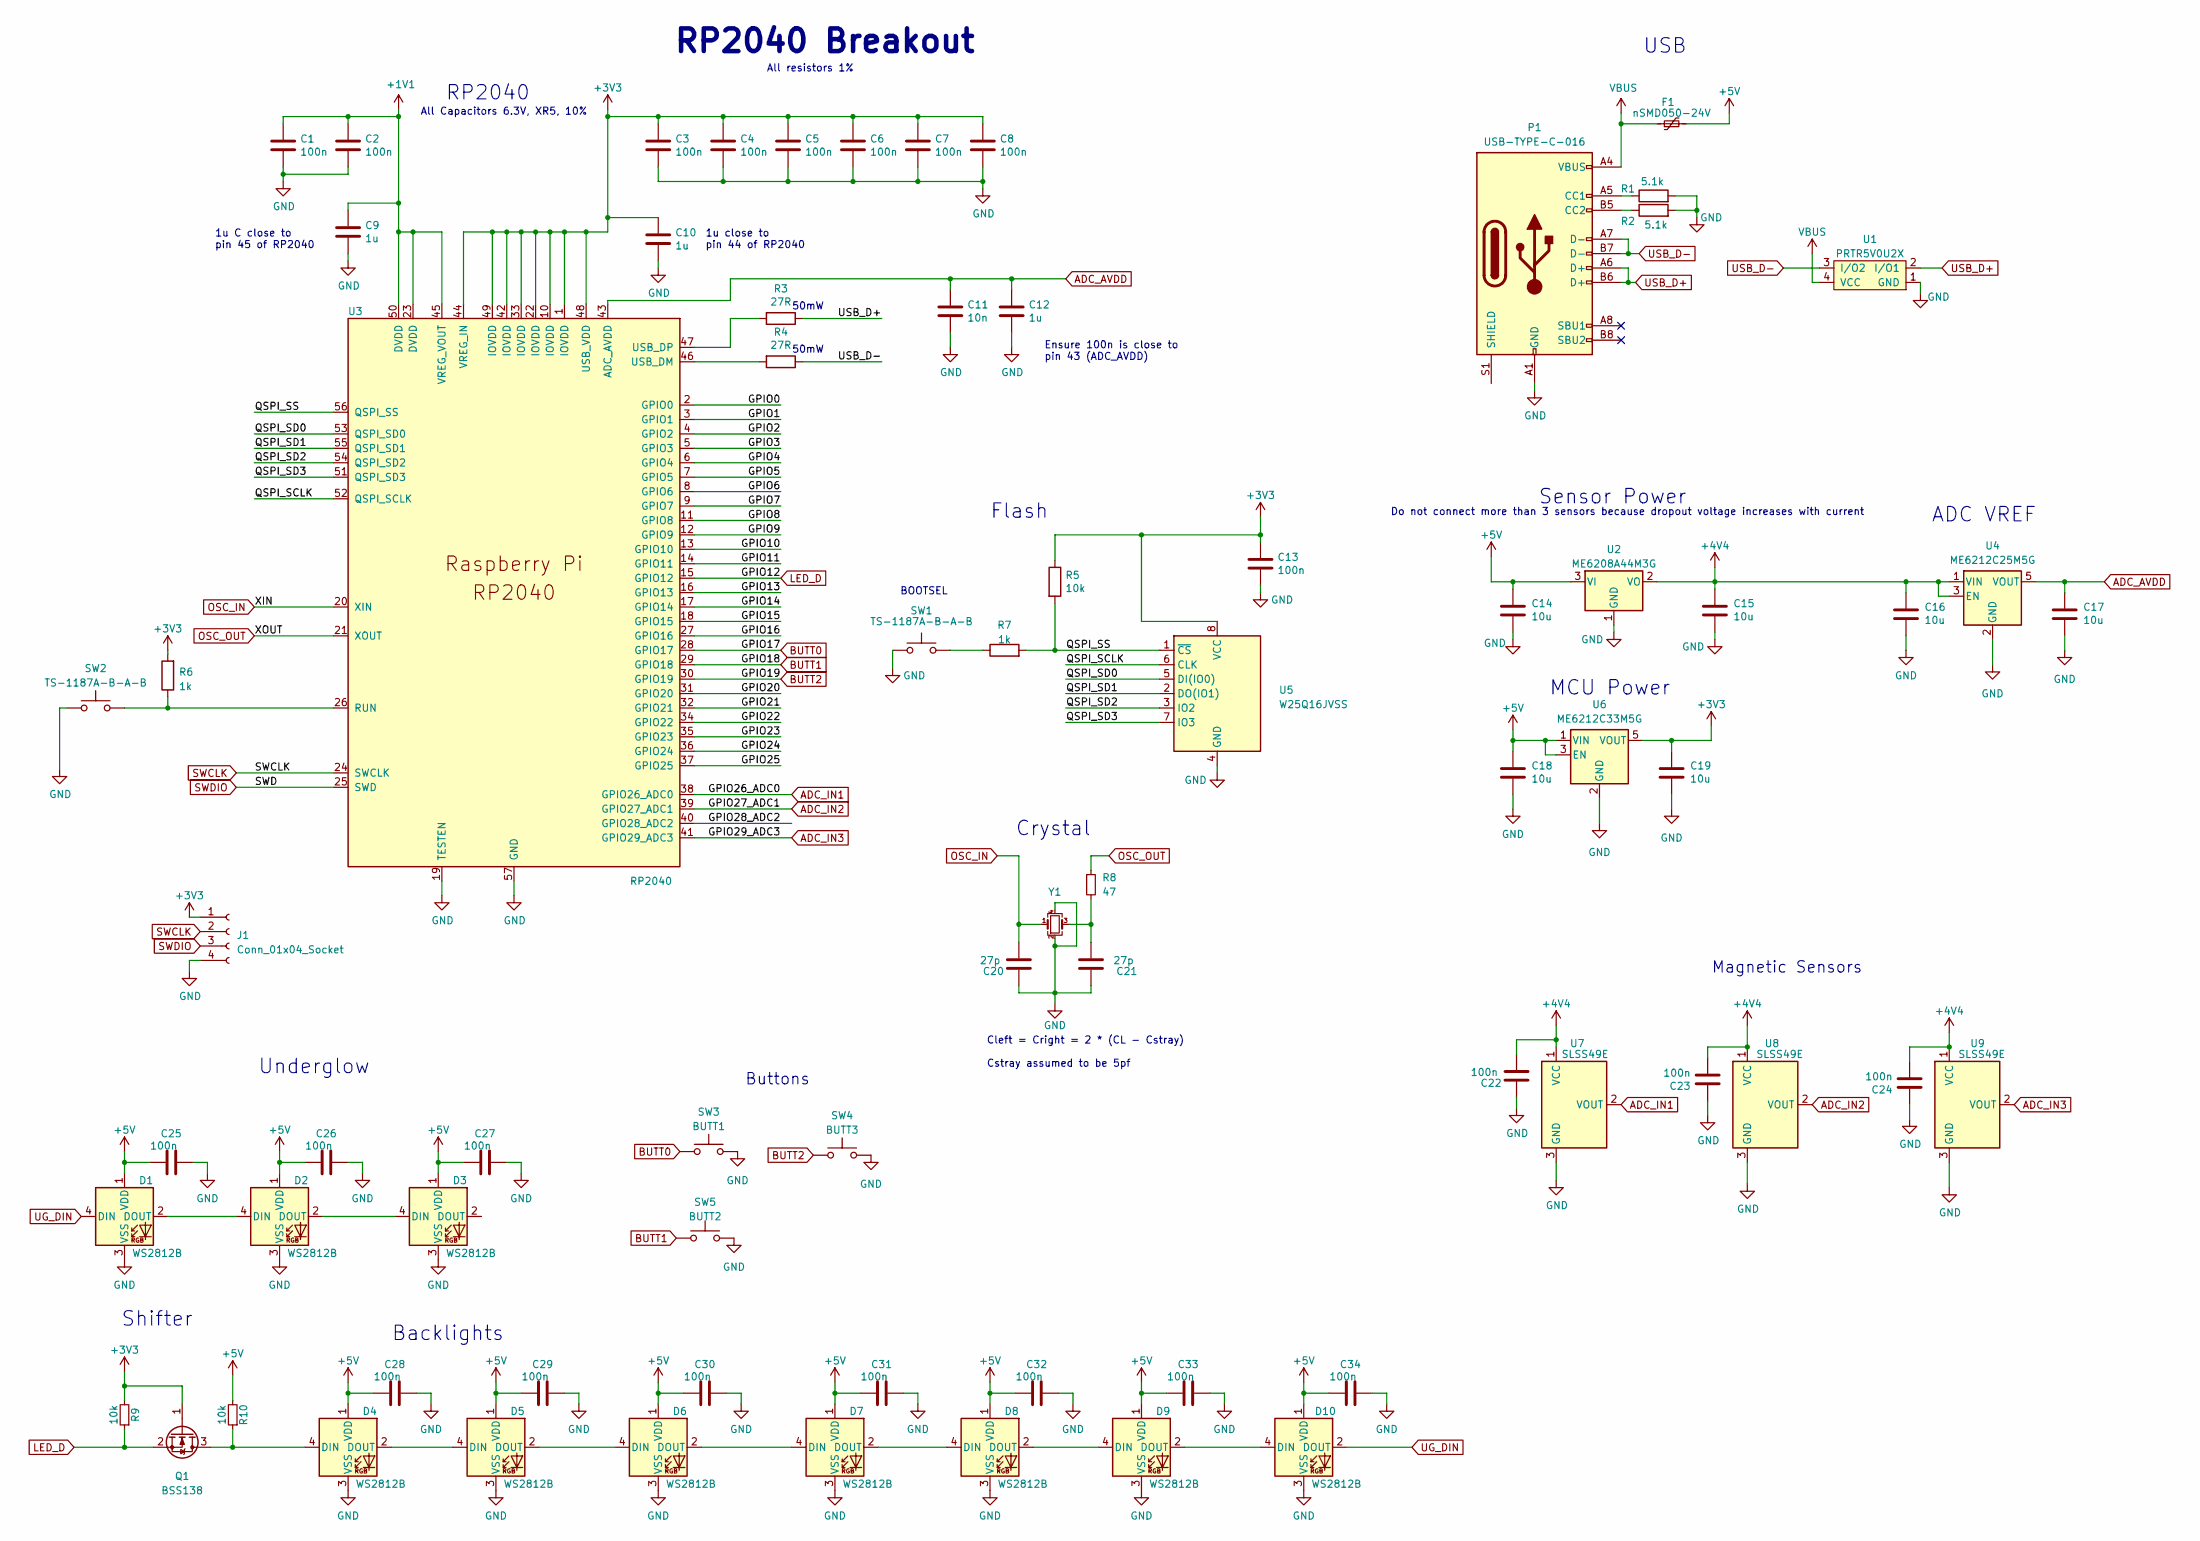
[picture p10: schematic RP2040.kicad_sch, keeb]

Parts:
C1, C2, C3, C4, C5, C6, C7, C8, C13, C22, C23, C24, C25, C26, C27, C28, C29, C30, C31, C32, C33, C34: 100n; C_0402_1005Metric
C9, C10, C12: 1u; C_0402_1005Metric
C11: 10n; C_0402_1005Metric
C14, C15, C16, C17, C18, C19: 10u; C_1206_3216Metric
C20, C21: 27p; C_0402_1005Metric
D1, D2, D3, D4, D5, D6, D7, D8, D9, D10: WS2812B; LED_WS2812B_PLCC4_5.0x5.0mm_P3.2mm
F1: nSMD050-24V; Fuse_1206_3216Metric
J1: Conn_01x04_Socket; PinSocket_1x04_P2.54mm_Vertical
P1: USB-TYPE-C-016; USB-TYPE-C-016_Receptacle_DEALON_16P_MidMnt
Q1: BSS138; SOT-23
R1, R2: 5.1k; C_0402_1005Metric
R3, R4: 27R; C_0402_1005Metric
R5: 10k; C_0402_1005Metric
R6, R7: 1k; C_0402_1005Metric
R8: 47; R_0402_1005Metric; LCSC Part # C25118
R9, R10: 10k; R_0402_1005Metric; LCSC Part # C25744
SW1, SW2: TS-1187A-B-A-B; TS-1187A
SW3: BUTT1; SW_Push_1P1T_NO_6x6mm_H9.5mm
SW4: BUTT3; SW_Push_1P1T_NO_6x6mm_H9.5mm
SW5: BUTT2; SW_Push_1P1T_NO_6x6mm_H9.5mm
U1: PRTR5V0U2X; SOT-143B
U2: ME6208A44M3G; SOT-23-3
U3: RP2040; RP2040-QFN-56
U4: ME6212C25M5G; SOT-23-5
U5: W25Q16JVSS; SOIC-8_5.23x5.23mm_P1.27mm
U6: ME6212C33M5G; SOT-23-5
U7, U8, U9: SLSS49E; SOT-23
Y1: 12MHz; Crystal_SMD_3225-4Pin_3.2x2.5mm; LCSC Part # C9002

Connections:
+1V1: C1.1, C2.1, C9.1, U3.23 (DVDD), U3.45 (VREG_VOUT), U3.50 (DVDD)
+3V3: C3.1, C4.1, C5.1, C6.1, C7.1, C8.1, C10.1, C13.1, C19.1, J1.1, Q1.1 (G), R5.1, R6.2, R9.2, U3.1 (IOVDD), U3.10 (IOVDD), U3.22 (IOVDD), U3.33 (IOVDD), U3.42 (IOVDD), U3.44 (VREG_IN), U3.48 (USB_VDD), U3.49 (IOVDD), U5.8 (VCC), U6.5 (VOUT)
+4V4: C15.1, C16.1, C22.2, C23.2, C24.2, U2.2 (VO), U4.1 (VIN), U4.3 (EN), U7.1 (VCC), U8.1 (VCC), U9.1 (VCC)
+5V: C14.1, C18.1, C25.1, C26.1, C27.1, C28.1, C29.1, C30.1, C31.1, C32.1, C33.1, C34.1, D1.1 (VDD), D2.1 (VDD), D3.1 (VDD), D4.1 (VDD), D5.1 (VDD), D6.1 (VDD), D7.1 (VDD), D8.1 (VDD), D9.1 (VDD), D10.1 (VDD), F1.2, R10.2, U2.3 (VI), U6.1 (VIN), U6.3 (EN)
/GPIO0: U3.2 (GPIO0)
/GPIO1: U3.3 (GPIO1)
/GPIO2: U3.4 (GPIO2)
/GPIO3: U3.5 (GPIO3)
/GPIO4: U3.6 (GPIO4)
/GPIO5: U3.7 (GPIO5)
/GPIO6: U3.8 (GPIO6)
/GPIO7: U3.9 (GPIO7)
/GPIO8: U3.11 (GPIO8)
/GPIO9: U3.12 (GPIO9)
/GPIO10: U3.13 (GPIO10)
/GPIO11: U3.14 (GPIO11)
/GPIO13: U3.16 (GPIO13)
/GPIO14: U3.17 (GPIO14)
/GPIO15: U3.18 (GPIO15)
/GPIO16: U3.27 (GPIO16)
/GPIO20: U3.31 (GPIO20)
/GPIO21: U3.32 (GPIO21)
/GPIO22: U3.34 (GPIO22)
/GPIO23: U3.35 (GPIO23)
/GPIO24: U3.36 (GPIO24)
/GPIO25: U3.37 (GPIO25)
/GPIO28_ADC2: U3.40 (GPIO28_ADC2)
/QSPI_SCLK: U3.52 (QSPI_SCLK), U5.6 (CLK)
/QSPI_SD0: U3.53 (QSPI_SD0), U5.5 (DI(IO0))
/QSPI_SD1: U3.55 (QSPI_SD1), U5.2 (DO(IO1))
/QSPI_SD2: U3.54 (QSPI_SD2), U5.3 (IO2)
/QSPI_SD3: U3.51 (QSPI_SD3), U5.7 (IO3)
/QSPI_SS: R5.2, R7.2, U3.56 (QSPI_SS), U5.1 (~CS)
ADC_AVDD: C11.1, C12.1, C17.1, U3.43 (ADC_AVDD), U4.5 (VOUT)
ADC_IN1: U3.38 (GPIO26_ADC0), U7.2 (VOUT)
ADC_IN2: U3.39 (GPIO27_ADC1), U8.2 (VOUT)
ADC_IN3: U3.41 (GPIO29_ADC3), U9.2 (VOUT)
BUTT0: SW3.1, U3.28 (GPIO17)
BUTT1: SW5.1, U3.29 (GPIO18)
BUTT2: SW4.1, U3.30 (GPIO19)
GND: C1.2, C2.2, C3.2, C4.2, C5.2, C6.2, C7.2, C8.2, C9.2, C10.2, C11.2, C12.2, C13.2, C14.2, C15.2, C16.2, C17.2, C18.2, C19.2, C20.1, C21.1, C22.1, C23.1, C24.1, C25.2, C26.2, C27.2, C28.2, C29.2, C30.2, C31.2, C32.2, C33.2, C34.2, D1.3 (VSS), D2.3 (VSS), D3.3 (VSS), D4.3 (VSS), D5.3 (VSS), D6.3 (VSS), D7.3 (VSS), D8.3 (VSS), D9.3 (VSS), D10.3 (VSS), J1.4, P1.A1 (GND), P1.A12 (GND), P1.B1 (GND), P1.B12 (GND), R1.2, R2.2, SW1.1, SW2.1, SW3.2, SW4.2, SW5.2, U1.1 (GND), U2.1 (GND), U3.19 (TESTEN), U3.57 (GND), U4.2 (GND), U5.4 (GND), U6.2 (GND), U7.3 (GND), U8.3 (GND), U9.3 (GND), Y1.2, Y1.4
LED_D: Q1.2 (S), R9.1, U3.15 (GPIO12)
unnamed: C21.2, R8.2, Y1.3
unnamed: D1.2 (DOUT), D2.4 (DIN)
unnamed: D2.2 (DOUT), D3.4 (DIN)
unnamed: D4.4 (DIN), Q1.3 (D), R10.1
unnamed: D4.2 (DOUT), D5.4 (DIN)
unnamed: D5.2 (DOUT), D6.4 (DIN)
unnamed: D6.2 (DOUT), D7.4 (DIN)
unnamed: D7.2 (DOUT), D8.4 (DIN)
unnamed: D8.2 (DOUT), D9.4 (DIN)
unnamed: D9.2 (DOUT), D10.4 (DIN)
unnamed: P1.A5 (CC1), R1.1
unnamed: P1.B5 (CC2), R2.1
unnamed: R7.1, SW1.2
unnamed: R6.1, SW2.2, U3.26 (RUN)
unnamed: R4.2, U3.46 (USB_DM)
unnamed: R3.2, U3.47 (USB_DP)
OSC_IN: C20.2, U3.20 (XIN), Y1.1
OSC_OUT: R8.1, U3.21 (XOUT)
SWCLK: J1.2, U3.24 (SWCLK)
SWDIO: J1.3, U3.25 (SWD)
UG_DIN: D1.4 (DIN), D10.2 (DOUT)
USB_D+: P1.A6 (D+), P1.B6 (D+), R3.1, U1.2 (I/O1)
USB_D-: P1.A7 (D-), P1.B7 (D-), R4.1, U1.3 (I/O2)
VBUS: F1.1, P1.A4 (VBUS), P1.A9 (VBUS), P1.B4 (VBUS), P1.B9 (VBUS), U1.4 (VCC)

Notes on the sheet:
Sensor Power
50mW
RP2040 Breakout
Do not connect more than 3 sensors because dropout voltage increases with current
Backlights
Crystal
ADC VREF
Magnetic Sensors
Underglow
All Capacitors 6.3V, XR5, 10%
USB
Flash
Ensure 100n is close to pin 43 (ADC_AVDD)
1u close to pin 44 of RP2040
1u C close to pin 45 of RP2040
All resistors 1%
MCU Power
Buttons
Shifter
RP2040
Cleft = Cright = 2 * (CL - Cstray) Cstray assumed to be 5pf
BOOTSEL

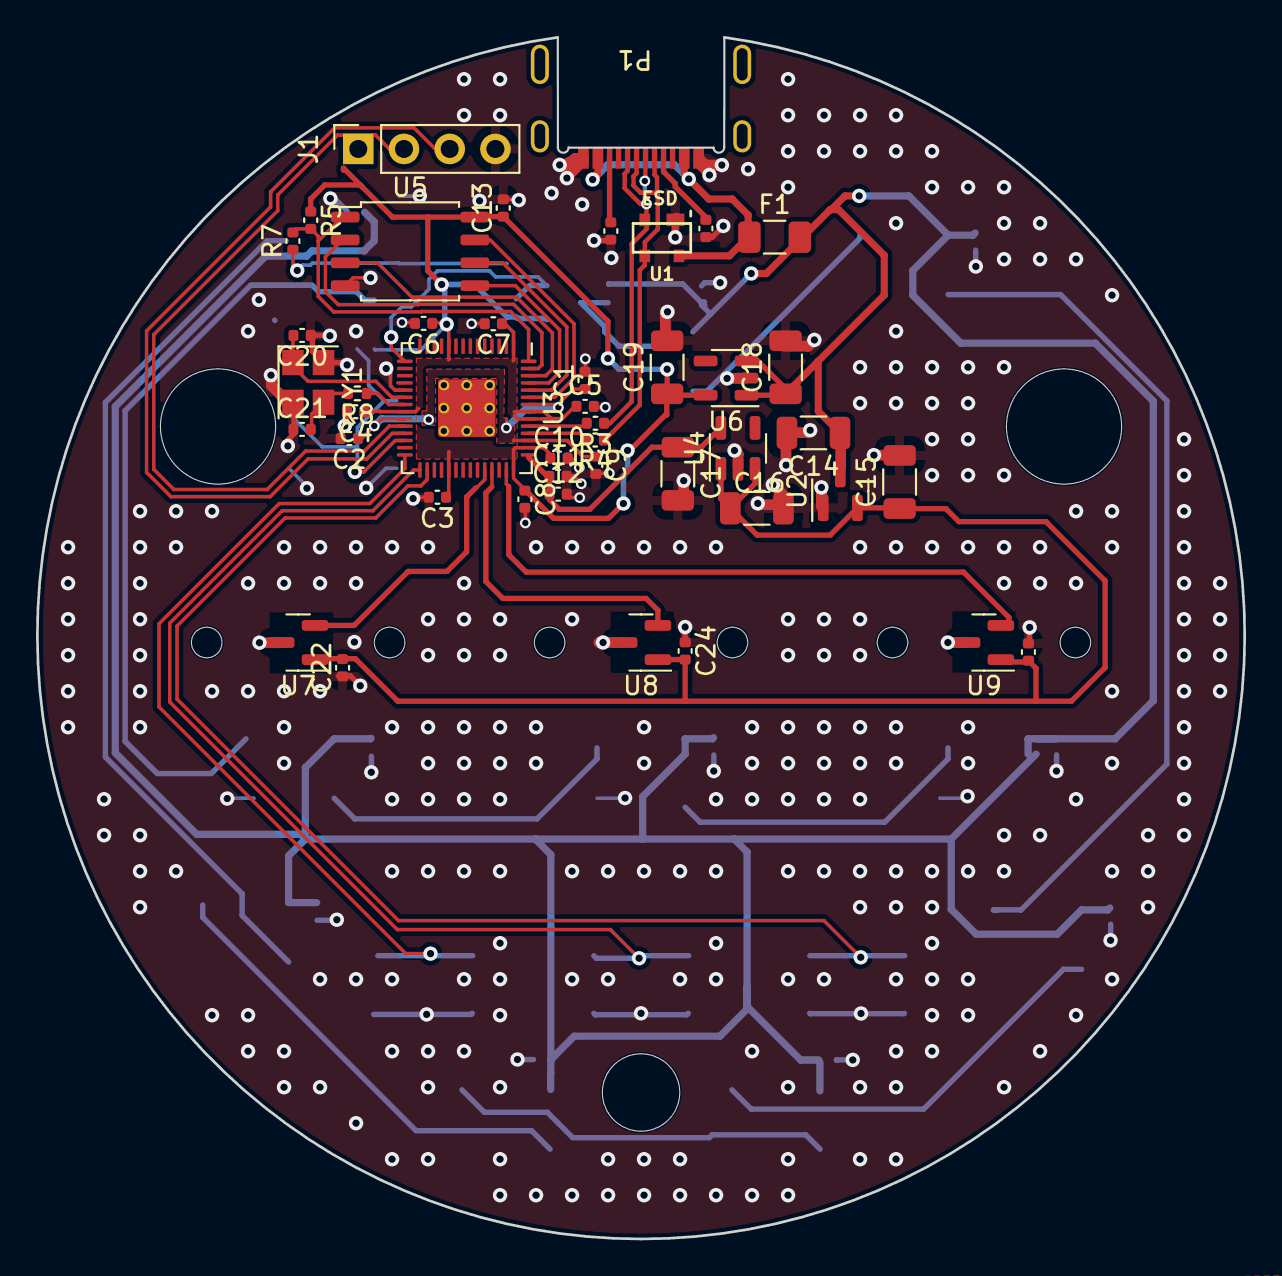
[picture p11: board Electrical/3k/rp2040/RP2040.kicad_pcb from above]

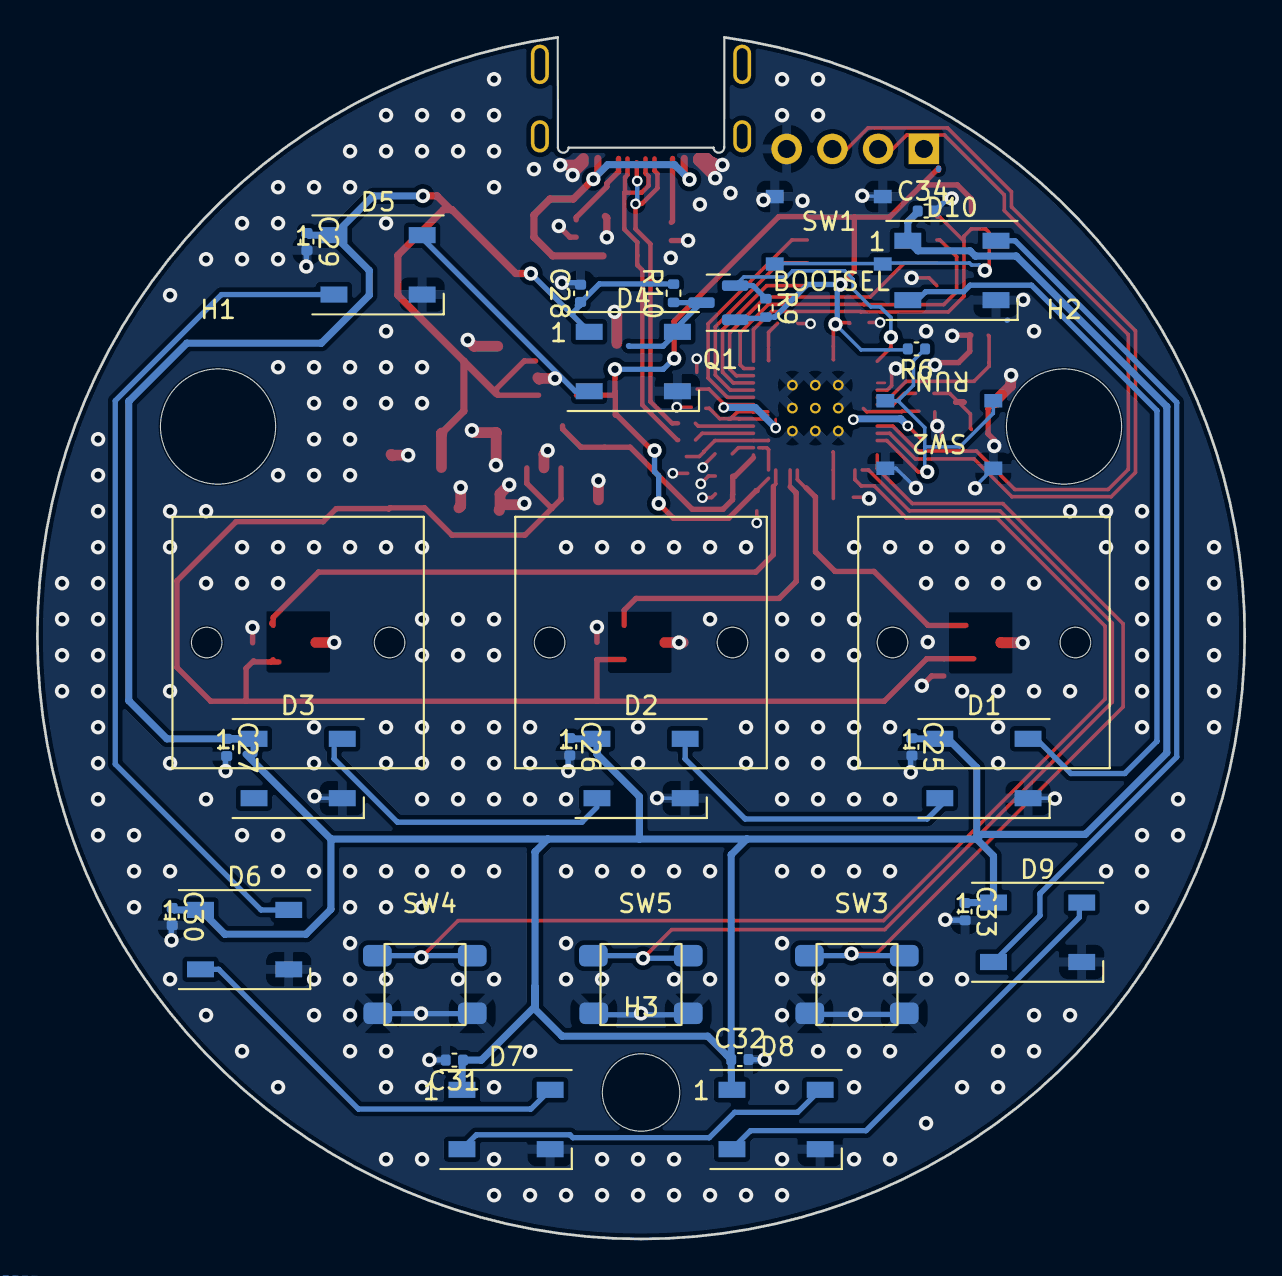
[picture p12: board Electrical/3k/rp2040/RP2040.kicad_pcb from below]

Board: 4 copper layers, 67.1 x 66.8 mm, 76 parts (32 on the bottom side), 43 nets.

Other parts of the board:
H1, H2: MountingHole_6.4mm_M6_DIN965
H3: MountingHole_4.3mm_M4_DIN965

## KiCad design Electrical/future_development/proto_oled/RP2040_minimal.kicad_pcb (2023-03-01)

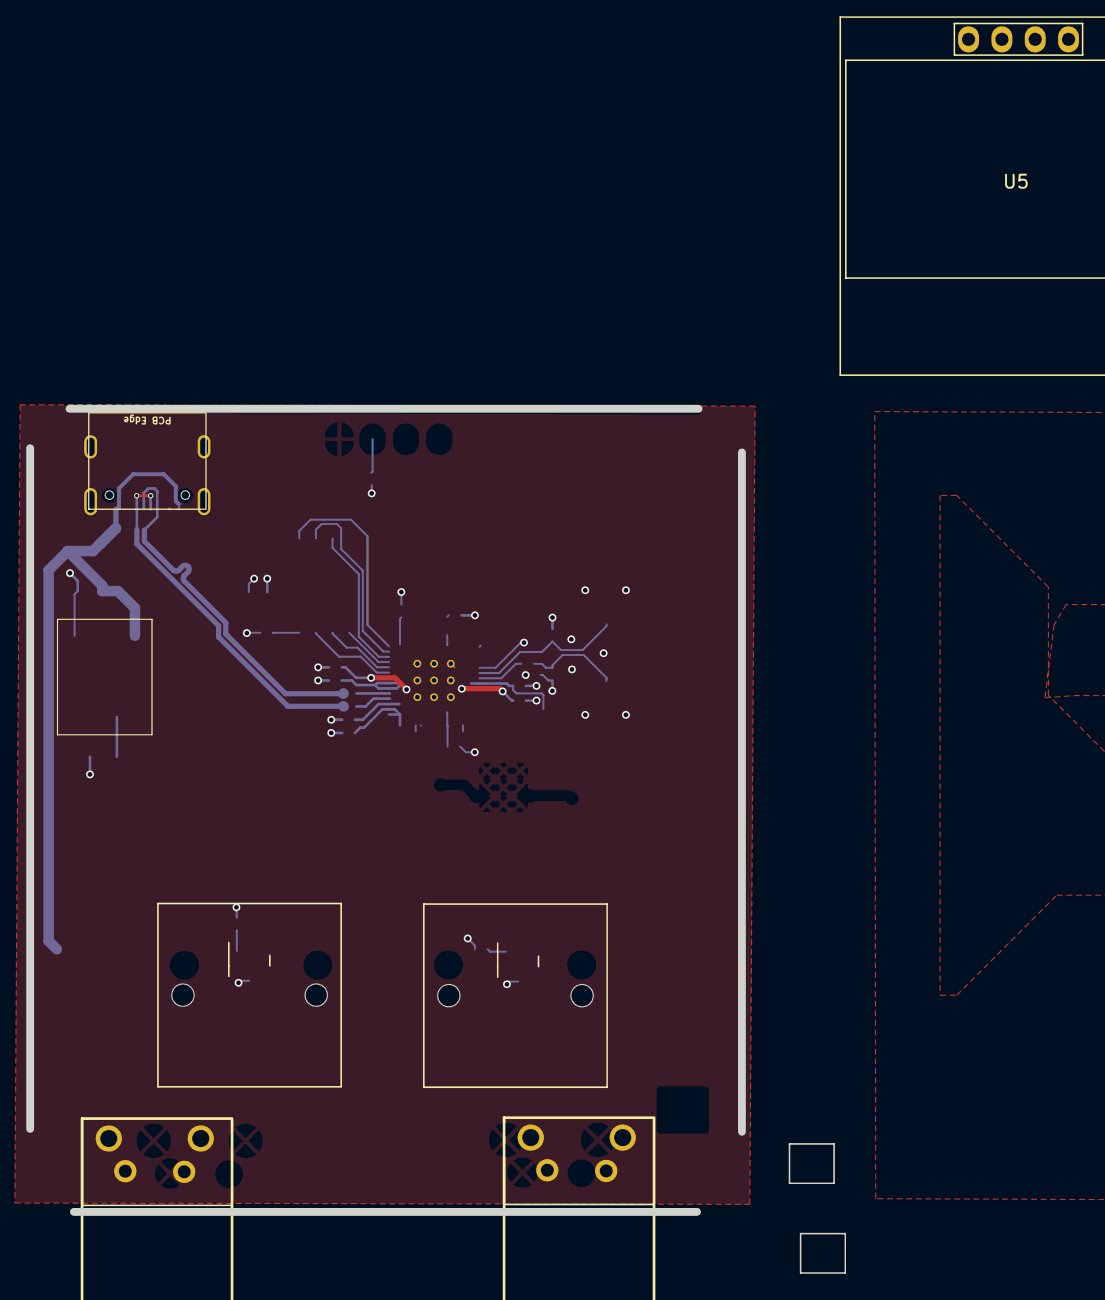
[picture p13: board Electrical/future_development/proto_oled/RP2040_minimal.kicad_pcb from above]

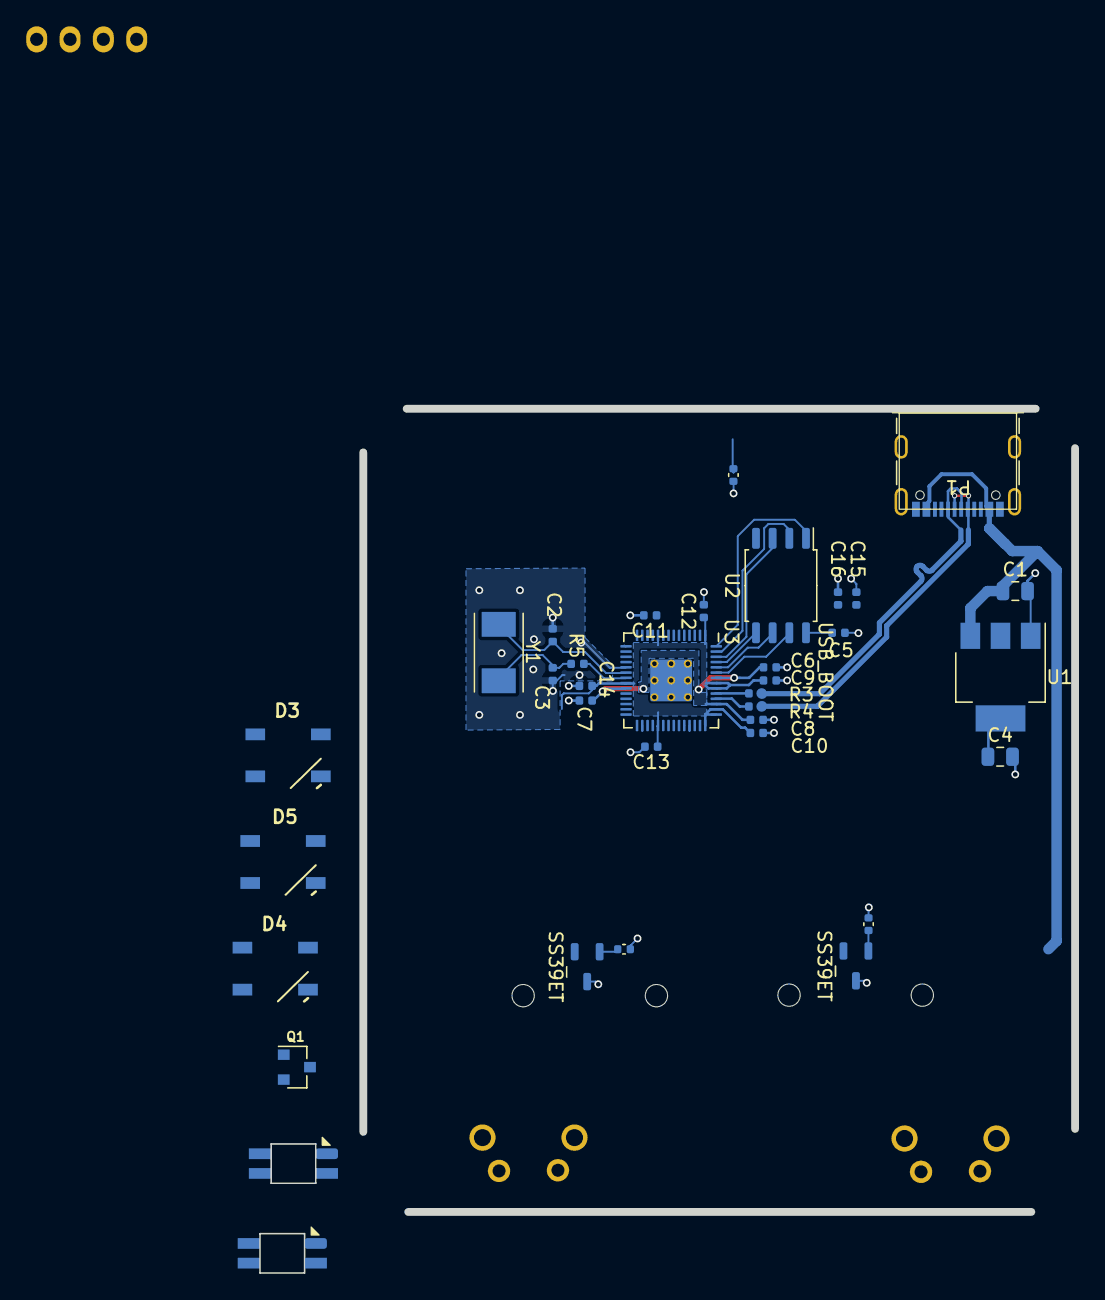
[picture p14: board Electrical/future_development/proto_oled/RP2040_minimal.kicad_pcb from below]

Board: 2 copper layers, 62.1 x 65.9 mm, 38 parts (35 on the bottom side), 21 nets.

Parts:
C1, C4: 10u; C_0805_2012Metric
C2, C3: 27p; C_0402_1005Metric
C5, C6, C7, C9, C11, C12, C13, C14, C15, C16: 100n; C_0402_1005Metric
C8, C10: 1u; C_0402_1005Metric
C21, C22, C23: C_0402_1005Metric
D1, D2: SK6812-MINI-E
D3, D4, D5: WS2812B
P1: USB_C_Receptacle_GCT_USB4105-xx-A_16P_TopMnt_Hori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; USB_C_Receptacle_GCT_USB4105-xx-A_16P_TopMnt_Horizontal
Q1: SOT-23
R3, R4: 27; C_0402_1005Metric
R5: 1k; C_0402_1005Metric
S1, S1#2: SS39ET; SOT-23-3
SW1, SW2: 2-1825027-0_Right_Angle_Switch-9.24mm_Stem; 2-1825027-0_Right_Angle_Button
U1: NCP1117-3.3_SOT223; SOT-223-3_TabPin2
U2: W25Q128JVS; SOIC-8_5.23x5.23mm_P1.27mm
U3: RP2040; RP2040-QFN-56
U5: 128x64OLED
Y1: ABLS-12.000MHZ-B4-T; Crystal_SMD_Abracon_ABM7-2Pin_6.0x3.5mm

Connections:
+1V1: C6.1, C7.1, C8.1, U3.23, U3.45, U3.50
+3V3: C4.1, C5.1, C9.1, C10.1, C11.1, C12.1, C13.1, C14.1, C15.1, C16.1, C21.1, C22.1, C23.1, S1.1, S1#2.1, U1.2, U2.8, U3.1, U3.10, U3.22, U3.33, U3.42, U3.43, U3.44, U3.48, U3.49, U5.2
/GPIO18: SW2.2, U3.29
/GPIO19: SW1.2, U3.30
/GPIO26_ADC0: S1.2, U3.38
/GPIO27_ADC1: S1#2.2, U3.39
/QSPI_SCLK: U2.6, U3.52
/QSPI_SD0: U2.5, U3.53
/QSPI_SD1: U2.2, U3.55
/QSPI_SD2: U2.3, U3.54
/QSPI_SD3: U2.7, U3.51
/QSPI_SS: U2.1, U3.56
/USB_D+: P1.A6, P1.B6, R3.1
/USB_D-: P1.A7, P1.B7, R4.1
/XIN: C2.1, U3.20, Y1.1
/XOUT: R5.1, U3.21
GND: C1.2, C2.2, C3.2, C4.2, C5.2, C6.2, C7.2, C8.2, C9.2, C10.2, C11.2, C12.2, C13.2, C14.2, C15.2, C16.2, C21.2, C22.2, C23.2, D3.3, D4.3, D5.3, P1.A1, P1.A12, P1.B1, P1.B12, S1.3, S1#2.3, SW1.1, SW1.3, SW1.4, SW2.1, SW2.3, SW2.4, U1.1, U2.4, U3.19, U3.57, U5.1
unnamed: C3.1, R5.2, Y1.2
unnamed: R3.2, U3.47
unnamed: R4.2, U3.46
VBUS: C1.1, D3.1, D4.1, D5.1, P1.A4, P1.A9, P1.B4, P1.B9, U1.3

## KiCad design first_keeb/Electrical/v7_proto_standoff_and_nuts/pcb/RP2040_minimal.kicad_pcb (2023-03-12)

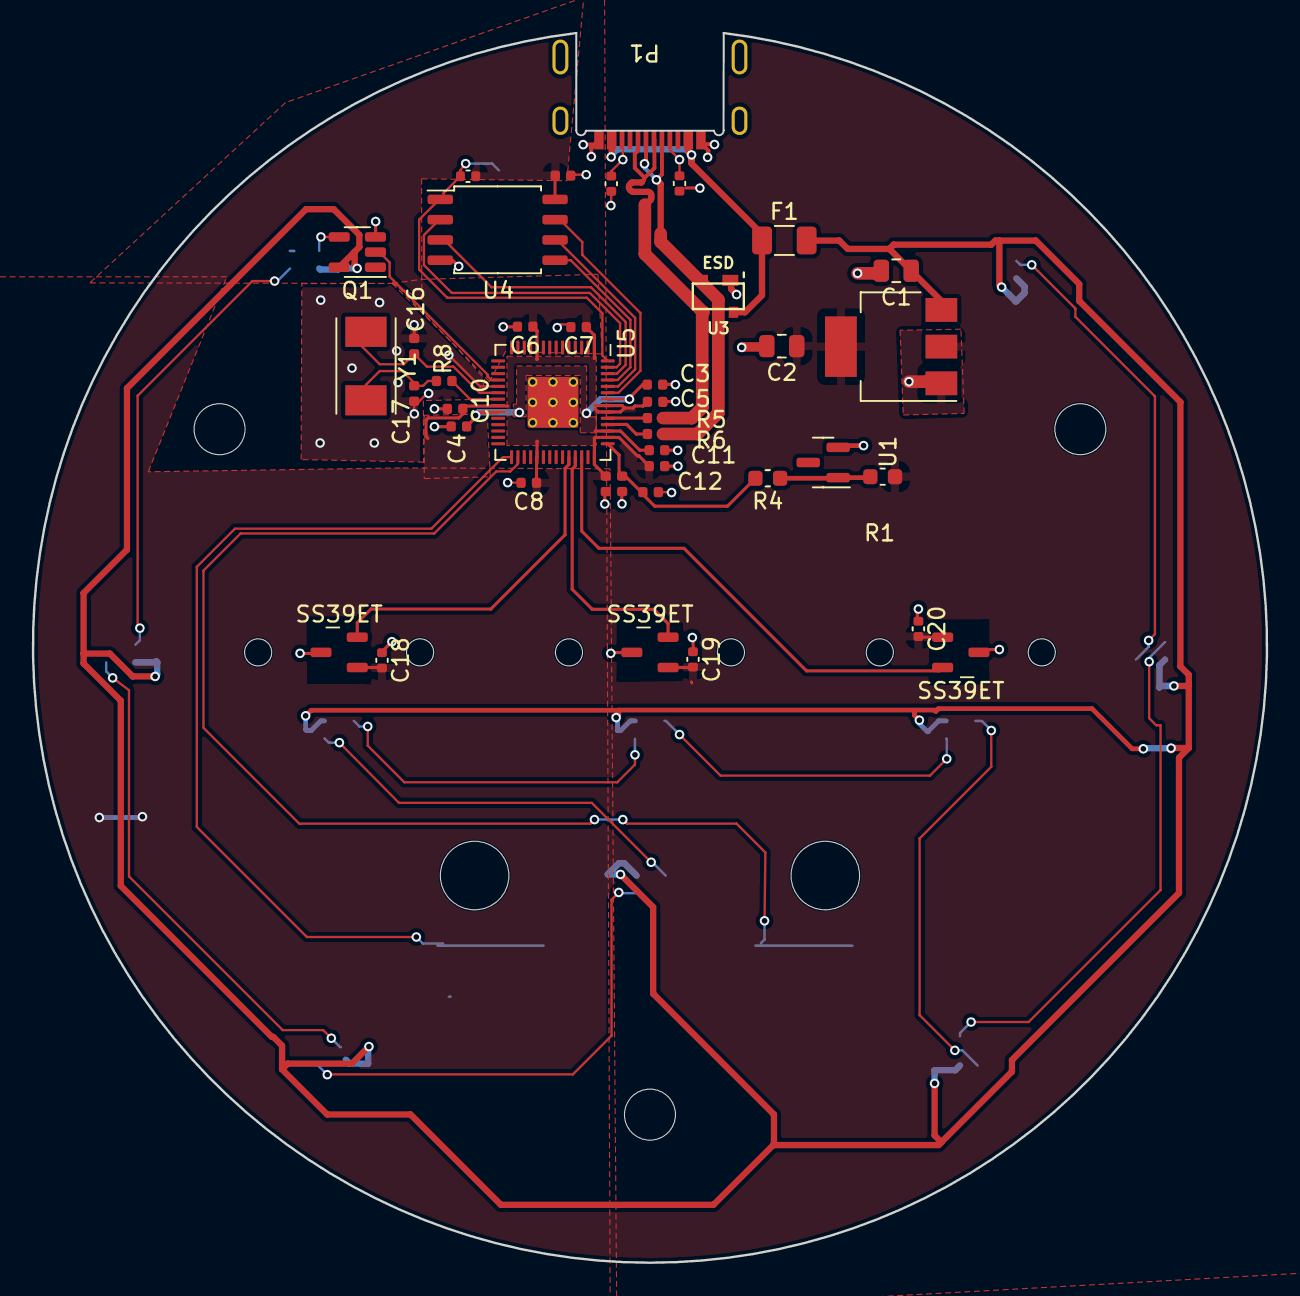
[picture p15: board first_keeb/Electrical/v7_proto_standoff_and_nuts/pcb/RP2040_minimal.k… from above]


Board: 2 copper layers, 77.4 x 77.1 mm, 68 parts (28 on the bottom side), 38 nets.

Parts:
C1, C2: 10u; C_0805_2012Metric
C3, C4, C5, C6, C7, C8, C9, C10, C13, C15, C21, C22, C23, C24, C25, C26, C27, C28, C29, C30: 100n; C_0402_1005Metric
C11, C12, C14, C18, C19, C20: 1u; C_0402_1005Metric
C16, C17: 27p; C_0402_1005Metric
D1, D2, D3, D4, D5, D6, D7, D8, D9, D10: WS2812B-2020; LED_WS2812B-2020_PLCC4_2.0x2.0mm
F1: nSMD025-24V; Fuse_1206_3216Metric
H1, H2, H3: MountingHole_3.2mm_M3
H4, H5: MountingHole_4.3mm_M4
P1: USB-TYPE-C-016; USB_C_Receptacle_DEALON_16P_MidMnt
Q1: SN74LV1T34DBV; SOT-23-5
R1: 200R; C_0603_1608Metric
R2, R3: 5.1k; C_0402_1005Metric
R4: 1R; C_0603_1608Metric
R5, R6: 27R; C_0402_1005Metric
R7: 10k; C_0402_1005Metric
R8: 1k; C_0402_1005Metric
S1, S2, S3: SS39ET; SOT-23-3
SW1: SKRKAGE020; SW_Push_SPST_NO_Alps_SKRK
SW2, SW3: PTS647 SN70 SMTR2 LFS; PTS647_4.5x4.5mm
U1: NCP1117-3.3_SOT223; SOT-223-3_TabPin2
U2: LM4040DBZ-3; SOT-23
U3: PRTR5V0U2X; SOT-143B
U4: W25Q32JVSS; SOIC-8_5.23x5.23mm_P1.27mm
U5: RP2040; RP2040-QFN-56
Y1: ABM7-12.000MHZ-D2Y-T; Crystal_SMD_Abracon_ABM7-2Pin_6.0x3.5mm

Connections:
+1V1: C3.1, C4.1, C11.1, U5.23 (DVDD), U5.45 (VREG_VOUT), U5.50 (DVDD)
+3V: R1.2, R4.1, U2.1 (K)
+3V3: C2.1, C5.1, C6.1, C7.1, C8.1, C9.1, C10.1, C12.1, C15.1, C18.2, C19.2, C20.2, R1.1, R7.1, S1.1 (VCC), S2.1 (VCC), S3.1 (VCC), U1.2 (VO), U4.8 (VCC), U5.1 (IOVDD), U5.10 (IOVDD), U5.22 (IOVDD), U5.33 (IOVDD), U5.42 (IOVDD), U5.44 (VREG_IN), U5.48 (USB_VDD), U5.49 (IOVDD)
+5V: C1.1, C21.1, C22.1, C23.1, C24.1, C25.1, C26.1, C27.1, C28.1, C29.1, C30.1, D1.4 (VDD), D2.4 (VDD), D3.4 (VDD), D4.4 (VDD), D5.4 (VDD), D6.4 (VDD), D7.4 (VDD), D8.4 (VDD), D9.4 (VDD), D10.4 (VDD), F1.2, Q1.5 (VCC), U1.3 (VI)
/QSPI_SCLK: U4.6 (CLK), U5.52 (QSPI_SCLK)
/QSPI_SD0: U4.5 (DI(IO0)), U5.53 (QSPI_SD0)
/QSPI_SD1: U4.2 (DO(IO1)), U5.55 (QSPI_SD1)
/QSPI_SD2: U4.3 (IO2), U5.54 (QSPI_SD2)
/QSPI_SD3: U4.7 (IO3), U5.51 (QSPI_SD3)
/QSPI_SS: R7.2, SW1.2, U4.1 (~CS), U5.56 (QSPI_SS)
/USB_D+: P1.A6, P1.B6, R5.1, U3.3 (I/O2)
/USB_D-: P1.A7, P1.B7, R6.1, U3.2 (I/O1)
/XIN: C16.1, U5.20 (XIN), Y1.1
/XOUT: R8.1, U5.21 (XOUT)
ADC_AVDD: C13.1, C14.1, R4.2, U5.43 (ADC_AVDD)
GND: C1.2, C2.2, C3.2, C4.2, C5.2, C6.2, C7.2, C8.2, C9.2, C10.2, C11.2, C12.2, C13.2, C14.2, C15.2, C16.2, C17.2, C18.1, C19.1, C20.1, C21.2, C22.2, C23.2, C24.2, C25.2, C26.2, C27.2, C28.2, C29.2, C30.2, D1.2 (GND), D2.2 (GND), D3.2 (GND), D4.2 (GND), D5.2 (GND), D6.2 (GND), D7.2 (GND), D8.2 (GND), D9.2 (GND), D10.2 (GND), P1.A1, P1.A12, P1.B1, P1.B12, Q1.3 (GND), R2.2, R3.2, S1.3 (GND), S2.3 (GND), S3.3 (GND), SW1.1, SW2.2, SW3.2, U1.1 (GND), U2.2 (A), U3.1 (GND), U4.4 (GND), U5.19 (TESTEN), U5.57 (GND)
GPIO18: SW2.1, U5.29 (GPIO18)
GPIO19: SW3.1, U5.30 (GPIO19)
LED_D_3V: Q1.2 (A), U5.18 (GPIO15)
LED_D_5V: D1.3 (DIN), Q1.4 (Y)
unnamed: C17.1, R8.2, Y1.2
unnamed: D1.1 (DOUT), D2.3 (DIN)
unnamed: D2.1 (DOUT), D3.3 (DIN)
unnamed: D3.1 (DOUT), D4.3 (DIN)
unnamed: D4.1 (DOUT), D8.3 (DIN)
unnamed: D5.1 (DOUT), D6.3 (DIN)
unnamed: D6.1 (DOUT), D7.3 (DIN)
unnamed: D8.1 (DOUT), D9.3 (DIN)
unnamed: D9.1 (DOUT), D10.3 (DIN)
unnamed: D5.3 (DIN), D10.1 (DOUT)
unnamed: P1.A5, R2.1
unnamed: P1.B5, R3.1
unnamed: R6.2, U5.46 (USB_DM)
unnamed: R5.2, U5.47 (USB_DP)
RP_ADC0: S1.2 (VOUT), U5.38 (GPIO26_ADC0)
RP_ADC1: S2.2 (VOUT), U5.39 (GPIO27_ADC1)
RP_ADC2: S3.2 (VOUT), U5.40 (GPIO28_ADC2)
VBUS: F1.1, P1.A4, P1.A9, P1.B4, P1.B9, U3.4 (VCC)

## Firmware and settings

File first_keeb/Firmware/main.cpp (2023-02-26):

#define _GNU_SOURCE
#include <cstdio>
#include <cstdlib>
#include <string>
#include <iostream>
#include <cstring>
#include <variant>
#include <vector>
#include <algorithm>

#include "hardware/adc.h"
#include "hardware/gpio.h"
#include "pico/stdlib.h"
#include "ws2812.pio.h"
#include "tusb_config.h"
#include "tusb.h"
#include "usb_descriptors.h"
#include "pico/multicore.h"
#include "pico/bootrom.h"
#include "hardware/flash.h"
#include <hardware/sync.h>
extern "C" {
#include "ssd1306/ssd1306.h"
}

#include "settings_util.h"
#include "menu.h"
#include "gpio_config.h"

Menu menu;
bool in_menu = false;

void init() {
    // init TinyUSB for HID reporting
    tusb_init();
    tud_init(BOARD_TUD_RHPORT);

    for (Input& input : inputs) {
        gpio_init(input.gpio);
        gpio_pull_up(input.gpio);
    }

    // init addressable LEDs
    PIO pio = pio0;
    uint offset = pio_add_program(pio, &ws2812_program);
    ws2812_program_init(pio, 0, offset, WS2812B_GPIO, 800000, false);
}

void read_input() {
    for (Input& input : inputs) {
        input.prev_pressed = input.pressed;
    }

    // eager debounce
    for (Input& input : inputs) {
        if (!gpio_get(input.gpio)) {
            input.last_time_pressed = time_us_64();
        }

        input.pressed = time_us_64() - input.last_time_pressed < debounce_wait_us;
    }
}

void send_keys() {
    // skip if HID not ready
    if (!tud_hid_ready()) {
        return;
    }

    static uint8_t keycode_prev[6] = { 0 };
    uint8_t keycode[6] = { 0 };

    for (int key_num = 0; key_num < NUM_KEYS; ++key_num) {
        if (inputs[key_num].pressed) {
            keycode[key_num] = inputs[key_num].hid_key;
        }
    }

    if (memcmp(keycode_prev, keycode, 6) != 0) {
        memcpy(keycode_prev, keycode, 6);
        tud_hid_keyboard_report(REPORT_ID_KEYBOARD, 0, keycode);
    }
}

// brightness in range 0-255. Values under 255 will lose resolution.
void put_pixel(uint8_t r, uint8_t g, uint8_t b, uint8_t brightness = 255) {
    r = r * brightness / 255;
    g = g * brightness / 255;
    b = b * brightness / 255;
    pio_sm_put_blocking(pio0, 0, (((uint32_t)(r) << 16) | ((uint32_t)(g) << 8) | (uint32_t)(b)) << 8u);
}

void handle_leds() {
    if (settings.rgb_mode == RGB_OFF) {
        return;
    }
    // send new data to LEDs every 500 microseconds
    static uint64_t last_message_time = time_us_64();
    if (time_us_64() > last_message_time + 500) {
        last_message_time = time_us_64();

        for (int key_num = 0; key_num <= NUM_KEYS; ++key_num) {
            if (inputs[key_num].pressed || settings.rgb_mode == RGB_STATIC) {
                put_pixel(settings.rgb_r, settings.rgb_g, settings.rgb_b);
            } else {
                put_pixel(0, 0, 0);
            }
        }
    }
}

void handle_display() {
    ssd1306_clear(&oled);

    if (in_menu) {
        uint32_t y = 0;
        for (std::string line : menu.get_display_strings()) {
            ssd1306_draw_string(&oled, 0, y, 1, line.c_str());
            y += 8;
        }
    } else {
        ssd1306_draw_string(&oled, 0, 0, 1, ("KEY0 press: " + std::to_string(inputs[KEY0].pressed)).c_str());
        ssd1306_draw_string(&oled, 0, 8, 1, ("KEY1 press: " + std::to_string(inputs[KEY1].pressed)).c_str());
    }

    ssd1306_show(&oled);
}

void oled_control_core_entry() {
    // init OLED
    i2c_init(oled_i2c, 3000000);
    gpio_set_function(OLED_SDA_GPIO, GPIO_FUNC_I2C);
    gpio_set_function(OLED_SCL_GPIO, GPIO_FUNC_I2C);
    gpio_pull_up(OLED_SDA_GPIO);
    gpio_pull_up(OLED_SCL_GPIO);
    oled.external_vcc = false;
    ssd1306_init(&oled, 128, 64, 0x3C, oled_i2c);

    // reset OLED
    ssd1306_clear(&oled);
    ssd1306_show(&oled);

    while (1) {
        while (core1_lockout) {
            sleep_ms(5); // idk why I need this but it freezes without it 
        }
        handle_display();
    }
}

bool newly_pressed(input_t input) { return inputs[input].pressed && !inputs[input].prev_pressed; }

void enter_menu() {
    menu.reset();
    while (1) {
        read_input();
        handle_leds();

        // implement slow moving hold later
        if (newly_pressed(BACK_BTN)) {
            // if we cannot go back, it means we are at the root menu, so exit the menu
            int went_back_to_directory = menu.go_back();
            if (!went_back_to_directory) {
                return;
            }
        } else if (newly_pressed(SELECT_BTN)) {
            menu.select();
        } else if (newly_pressed(KEY0)) {
            menu.key_0_event();
        } else if (newly_pressed(KEY1)) {
            menu.key_1_event();
        }
    }
}

void handle_bootsel() {
    // TODO have user hold bootsel button for 1 second instead of instantly executing it.
    if (inputs[BOOTSEL_BTN].pressed) {
        // GPIO 1 will be HIGH when in bootsel mode
        reset_usb_boot(1, 0);
    }
}

int main() {
    init();
    settings = get_settings();
    multicore_launch_core1(oled_control_core_entry);

    while (1) {
        tud_task(); // have to do this for TinyUSB
        read_input();
        send_keys();
        handle_leds();
        handle_bootsel();
        if (inputs[SELECT_BTN].pressed) {
            in_menu = true;
            enter_menu();
            in_menu = false;
        }
    }
}

// Not using the following callbacks:

// Invoked when received GET_REPORT control request
// Application must fill buffer report's content and return its length.
// Return zero will cause the stack to STALL request
uint16_t tud_hid_get_report_cb(uint8_t instance, uint8_t report_id, hid_report_type_t report_type, uint8_t* buffer, uint16_t reqlen) { return 0; }

// Invoked when received SET_REPORT control request or
// received data on OUT endpoint ( Report ID = 0, Type = 0 )
void tud_hid_set_report_cb(uint8_t instance, uint8_t report_id, hid_report_type_t report_type, uint8_t const* buffer, uint16_t bufsize) { }

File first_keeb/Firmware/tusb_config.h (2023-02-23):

/*
 * The MIT License (MIT)
 *
 * Copyright (c) 2019 Ha Thach (tinyusb.org)
 *
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
 */

#ifndef _TUSB_CONFIG_H_
#define _TUSB_CONFIG_H_

#ifdef __cplusplus
extern "C" {
#endif

    //--------------------------------------------------------------------+
    // Board Specific Configuration
    //--------------------------------------------------------------------+

    // RHPort number used for device can be defined by board.mk, default to port 0
#ifndef BOARD_TUD_RHPORT
#define BOARD_TUD_RHPORT      0
#endif

// RHPort max operational speed can defined by board.mk
#ifndef BOARD_TUD_MAX_SPEED
#define BOARD_TUD_MAX_SPEED   OPT_MODE_DEFAULT_SPEED
#endif

//--------------------------------------------------------------------
// COMMON CONFIGURATION
//--------------------------------------------------------------------

// defined by compiler flags for flexibility
#ifndef CFG_TUSB_MCU
#error CFG_TUSB_MCU must be defined
#endif

#ifndef CFG_TUSB_OS
#define CFG_TUSB_OS           OPT_OS_NONE
#endif

#ifndef CFG_TUSB_DEBUG
#define CFG_TUSB_DEBUG        0
#endif

// Enable Device stack
#define CFG_TUD_ENABLED       1

// Default is max speed that hardware controller could support with on-chip PHY
#define CFG_TUD_MAX_SPEED     BOARD_TUD_MAX_SPEED

/* USB DMA on some MCUs can only access a specific SRAM region with restriction on alignment.
 * Tinyusb use follows macros to declare transferring memory so that they can be put
 * into those specific section.
 * e.g
 * - CFG_TUSB_MEM SECTION : __attribute__ (( section(".usb_ram") ))
 * - CFG_TUSB_MEM_ALIGN   : __attribute__ ((aligned(4)))
 */
#ifndef CFG_TUSB_MEM_SECTION
#define CFG_TUSB_MEM_SECTION
#endif

#ifndef CFG_TUSB_MEM_ALIGN
#define CFG_TUSB_MEM_ALIGN          __attribute__ ((aligned(4)))
#endif

 //--------------------------------------------------------------------
 // DEVICE CONFIGURATION
 //--------------------------------------------------------------------

#ifndef CFG_TUD_ENDPOINT0_SIZE
#define CFG_TUD_ENDPOINT0_SIZE    64
#endif

//------------- CLASS -------------//
#define CFG_TUD_HID               1
#define CFG_TUD_CDC               0
#define CFG_TUD_MSC               0
#define CFG_TUD_MIDI              0
#define CFG_TUD_VENDOR            0

// HID buffer size Should be sufficient to hold ID (if any) + Data
#define CFG_TUD_HID_EP_BUFSIZE    16

#ifdef __cplusplus
}
#endif

#endif /* _TUSB_CONFIG_H_ */

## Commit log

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2023-02-21 add MCU, i2c pullup, and oled to sch
    [first_keeb.kicad_sch]
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2023-02-21 fixes i2c and moves them to gpio that can only do i2c. Adds pico pinout picture
    [first_keeb.kicad_sch]
2023-02-21 fix dotted lines
    [first_keeb.kicad_sch]
2023-02-22 adds jumper configuration to select any voltage source for testing purposes
    [first_keeb.kicad_sch]
2023-02-22 improve jumper config circuit
    [first_keeb.kicad_sch]
2023-02-22 adds a lot of new things to schematic
    [first_keeb.kicad_sch]
2023-02-22 ready to start frist pcb
    [first_keeb.kicad_sch]
2023-02-23 finish v1 pcb, and generate drill file+plot
    [first_keeb-B_Cu.gbr, first_keeb-B_Mask.gbr, first_keeb-B_Paste.gbr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]
2023-02-23 adds right angle switch to pcb and plots gerbers
    [first_keeb-B_Cu.gbr, first_keeb-B_Mask.gbr, first_keeb-B_Paste.gbr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]
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2023-02-23 add gnd pour on back layer
    [first_keeb-B_Cu.gbr, first_keeb-B_Mask.gbr, first_keeb-B_Paste.gbr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]
2023-02-23 fixes gnd plane issues on pcb
    [first_keeb-B_Cu.gbr, first_keeb-B_Mask.gbr, first_keeb-B_Paste.gbr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]
2023-02-23 fix ground plane issues
    [first_keeb-B_Cu.gbr, first_keeb-B_Mask.gbr, first_keeb-B_Paste.gbr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]
2023-02-23 remove unused via to gnd
    [first_keeb-B_Cu.gbr, first_keeb-B_Mask.gbr, first_keeb-B_Paste.gbr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]
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2023-02-25 fix the edgiest case and refactor inputs
    [main.cpp]
2023-02-28 lays out all non-gpio connections to rp2040
    [RP2040_minimal.kicad_pcb, RP2040_minimal.kicad_sch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]
2023-02-28 script for recovering staged local changes I accidentally delete when running `git reset --hard` instead of `git reset --soft`. The script can only retrieve changes that were staged or commited.
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2023-03-02 finishes proto_v2 board. Set up some stuff to automate jlcpcb format for pcb assembly
    [RP2040_minimal-B_Cu.gbr, RP2040_minimal-B_Mask.gbr, RP2040_minimal-B_Paste.gbr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]
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2023-03-04 ads bootsel button and changes pcb to 80mm diameter
    [RP2040_minimal.kicad_pcb, RP2040_minimal.kicad_sch]
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2023-03-07 v1 pcb with backlights and underglow. started case designs
    [3holes.FCStd, BOM-RP2040_minimal.csv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]
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2023-03-08 makes countersink on bottom of case pi/4 rad, and starts the plate
    [BOM-RP2040_minimal.csv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]
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2023-03-10 creates a board that uses mid-mount usbc receptacle, and has all the rp2040 circuitry on the opposite layer of keyboard switches so that foam mod can be made easily. Also adds the threaded inserts
    [BOM-RP2040_minimal.csv, Counter_Sink_single_piece_case-Body.stl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]
2023-03-10 make room for weights under pcb lower half
    [RP2040_minimal.kicad_pcb, single_piece_case.FCStd, square_nut_single_piece_case-Body.stl]
2023-03-11 adds another option for pcb with threaded insert
    [BOM-RP2040_minimal.csv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]
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2023-03-12 have top mount, and mid mount receptacle cases
    [single_piece_case.FCStd, v1_single_body_case.stl, v1_top_receptacle_single_body_case.stl]
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2023-03-13 add printing profile and some test printing stuff
    [chamfer.stl, single_piece_case.FCStd, testing.stl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]
2023-03-15 adds 2 layer and 4 layer pcb versions
    [BOM-RP2040_minimal.csv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]
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2023-03-18 add leds and fix rapid trigger
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2023-03-25 improve power routing to go around analog signals
    [RP2040_minimal.kicad_pcb]
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2023-03-26 fixes lcsc number in bom
    [BOM-RP2040_minimal.csv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]
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2023-03-28 - no more tan caps - adds 1u before ferrite - ties ties other side of boot0 resistor to gnd
    [RP2040_minimal.kicad_pcb, RP2040_minimal.kicad_sch, mid-mount-no-guide.stl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]
2023-03-28 fix mag sensor schematic
    [RP2040_minimal.kicad_pcb, RP2040_minimal.kicad_sch]
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2023-03-31 stm fixes, still has different voltages
    [BOM-RP2040_minimal.csv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]
2023-04-01 changes to ws2812b 5050 and moves 5v power rail to mostly 4th layer
    [RP2040_minimal.kicad_pcb, RP2040_minimal.kicad_sch]
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2023-04-13 moves pcb components down to make more space, and fixes case
    [RP2040_minimal-CuBottom.gbr, RP2040_minimal-CuTop.gbr, RP2040_minimal-EdgeCuts.gbr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]
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2023-04-23 create separate folders for rp2040 and stm32 designs
    [BOM-RP2040_minimal.csv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]
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2023-04-23 switches swdio and swclk on stm to match rp2040
    [RP2040_minimal.kicad_pcb, RP2040_minimal.kicad_sch]
2023-04-23 adds 10n and 100n capactiros near rp2040 adc_avdd
    [RP2040_minimal.kicad_pcb, RP2040_minimal.kicad_sch]
2023-04-23 puts 10n and 1u caps to decouple adv_avdd on rp2040 to match the stm32 adc vref
    [RP2040_minimal.kicad_pcb, RP2040_minimal.kicad_sch]
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2023-04-24 fixes rp2040 board, stm32 board still todo
    [BOM-RP2040.csv, BOM-STM32.csv, BOM-plate.csv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]
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2023-04-27 adds small moat to case to prevent line from forming on outside of case when 3d printed.
    [case.FCStd, case.stl]
2023-04-27 fixes case heights and makes the final case
    [case-Body-r40.stl, case-Body-r40_1.stl, case.FCStd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]
2023-04-28 creates 3mf 3d print config files for case
    [CE3E3V2_case-Body-r40_1.3mf, CE3E3V2_case-Body.3mf]
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2023-07-01 creates outline with screw and 3d printed standoffs, and space for panelization mousebites to be put for better case fit.
    [RP2040.kicad_pcb, edge-cuts-Shape.dxf, edge-cuts.FCStd]
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2023-07-14 adds screw holes to stabilize pcb
    [RP2040-CuBottom.gbr, RP2040-CuIn1.gbr, RP2040-CuIn2.gbr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]
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2023-07-16 creates 3mf with supports that are easier to remove
    [case-Body-array.3mf, case-Body.3mf, case-Body.stl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]
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2023-10-07 uses backlight to refer to individual key lights, and underglow for the rest
    [RP2040.kicad_pcb, RP2040.kicad_sch]
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2023-10-09 finishes rp2040 2 layer board with split gnd
    [BOM-RP2040.csv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]
2023-10-31 finishes 4 layer split gnd rp2040 board. tested and saw that noise is worse with split gnd when compared to connected GND
    [RP2040-CuBottom.gbr, RP2040-CuIn1.gbr, RP2040-CuIn2.gbr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]
2023-12-04 adds comments for mousebite locations and changes via stitching spacing to 2.54mm
    [RP2040.kicad_pcb]
2023-12-04 removes all power supplies except 3v3 and moves some things around in schematic
    [BOM-RP2040.csv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]
2023-12-07 add HE sensor keepout zone to all layers
    [RP2040.kicad_pcb]
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2024-03-10 adds all circuit components needed for final pcb, but may need more LED
    [RP2040.kicad_pcb, RP2040.kicad_sch]
2024-03-11 reverts to using standard bs138 because the dual package one is more expensive than just using two of them, and it's easier to layout
    [RP2040.kicad_pcb, RP2040.kicad_sch]
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2024-03-11 adds 2020 led to smoothen out LED diffusing on sides
    [RP2040.kicad_pcb, RP2040.kicad_sch]
2024-03-12 adds instructions to readme, adds the button changes to plate
    [RP2040.kicad_pcb, case.FCStd, edge-cuts-Shape.dxf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]
2024-03-21 adds some height to standoffs so that switches sit more comfortably, and changes nut holes to square
    [case-Body.stl, case.FCStd]
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2024-03-22 changes led per-key backlights to 2020 and adds more screw holes for tilting issue
    [RP2040.kicad_pcb, RP2040.kicad_sch]
2024-03-22 fixes stray via
    [RP2040.kicad_pcb]
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2024-03-22 changes trace width of analog signals to be 0.3
    [RP2040.kicad_pcb]
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2024-03-22 dodge the screw holes so that the signals never have a chance of touching the metal screws
    [RP2040.kicad_pcb]
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2024-03-22 misc fixes and gen jlc gerber
    [CPL-RP2040.csv, RP2040-CuBottom.gbr, RP2040-CuIn1.gbr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]
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2024-03-28 switches back to 1 data pin for LED
    [BOM-RP2040.csv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]
2024-03-28 fixes up power traces
    [RP2040.kicad_pcb]
